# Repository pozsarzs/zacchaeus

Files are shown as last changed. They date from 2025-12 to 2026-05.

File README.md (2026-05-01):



# Zacchaeus Microcomputer
**8-bit microcomputer built from commercially available and home-built components**  

This project is a personal journey back in time to the heroic age of computing:
a newly built, classic 8-bit system, in which I supplement the factory components
with modules of my own design. My goal is to revive the joy of discovery, while
on this new machine, legendary languages such as BASIC, Fortran or Cobol come to
life again.

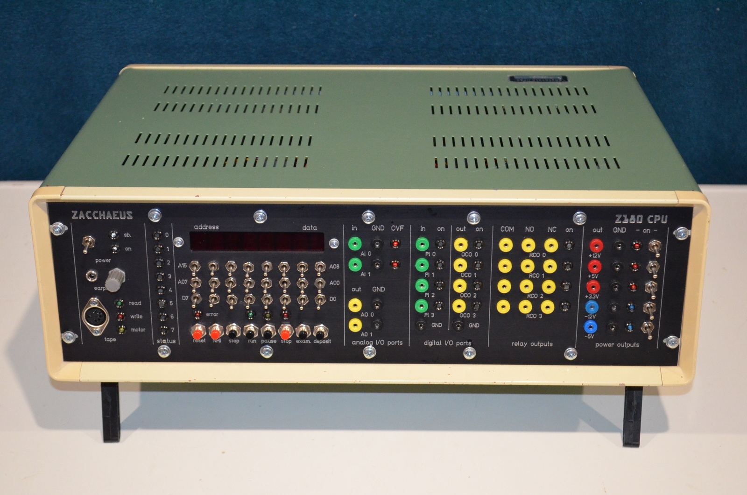
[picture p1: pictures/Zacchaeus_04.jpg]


The computer is built on a motherboard based on the Z180 processor and expansion
cards designed by Stephen C. Cousins. These component descriptions are provided
for completeness and represent the versions available at the time of use.
For more detailed descriptions and the latest updates, please visit the original
author's website ([Small Computer Central](https://smallcomputercentral.com/)).
These components are licensed as _open source_ and _public domain_.

These components are complemented by custom-designed expansion cards and
external peripherals. The custom-designed software are licensed as
_open source_ and hardware are licensed as _public domain_.  

A detailed description of the computer can be found in the
[Zacchaeus computer](https://github.com/pozsarzs/zacchaeus/tree/main/Zacchaeus%20computer) folder.

## External interface box

PEIX is an 8-slot interface connecting legacy _Klöckner-Moeller PS316_ I/O modules
to the Zacchaeus computer via RS-232 serial line with SCRAP protocol. It restores
functionality to these obsolete analog and digital modules.

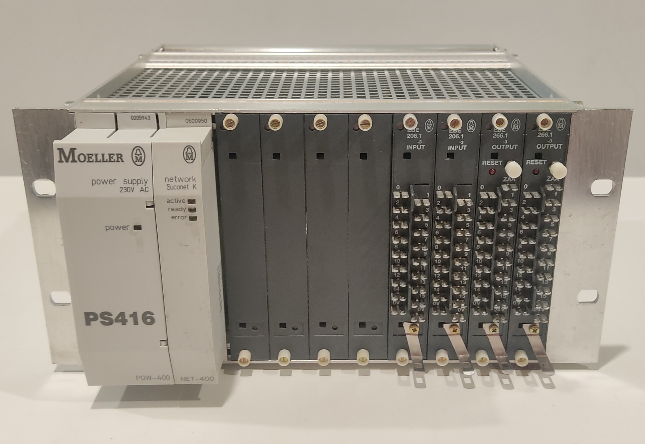
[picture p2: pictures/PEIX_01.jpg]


A detailed description of the interface box can be found in the
[PEIX External interface box](https://github.com/pozsarzs/zacchaeus/tree/main/PEIX%20External%20interface%20box) folder.

## External memory box (EPROM bank)

PEMX is an 8-slot external EPROM bank connected via two PIO ports. It supports
2764 through 27512 EPROMs, including 'A' and CMOS variants with raw data and
lowFAT filesystem.

A detailed description of the memory box can be found in the
[PEMX External memory box](https://github.com/pozsarzs/zacchaeus/tree/main/PEMX%20External%20memory%20box) folder.

---

### My related projects on Github

- [An extended Turing machine implementation for CP/M and DOS](https://github.com/pozsarzs/alanz80x)
- [Turing machine implementation for CP/M and DOS](https://github.com/pozsarzs/alanz80)
- [Simulator for running DATAS machine code for CP/M and DOS](https://github.com/pozsarzs/datassim)
- [The FORTRAN Month](https://github.com/pozsarzs/fortran_month)
- [Synchronized Client Register Access Protocol](https://github.com/pozsarzs/scrap)
- [R128 filesystem](https://github.com/pozsarzs/r128fs)

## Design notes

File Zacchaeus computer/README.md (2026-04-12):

# Zacchaeus Microcomputer
  
## Features

|components |type, size, etc. |
|---|---|
|motherboard |SC126 |
|firmware |RomWBW SCZ180_sc126 v3.5.1 2025-05-21 |
|processor |Z180 processor (33 MHz - at 18.432 MHz) |
|ROM |2 x 512 kB byte Flash memory |
|RAM |512 kB byte RAM |
|bus |BP80 (extended RC2014 bus), 9 sockets |
|disks |32 MB CF card |
| |SD card |
|others |RTC |
|control panel |8 digits hexadecimal LED display |
| |8 data input switch |
| |16 address input switch |
| |8 control button |
|front connectors|1 x tape |
| |1 x earphone |
| |4 x protected digital input 12V |
| |4 x open collector output |
| |4 x NO/NC relay contact output |
| |2 x analog input 0-10V |
| |2 x analog output 0-10V |
| |+12/5/3.3V 3A power outputs |
| |-12/5V 0.5A power outputs |
|back connectors |2 x serial RS-232 (DB9M black) |
| |2 x serial RS-232 TTL (DB9M and DB25M blue)  |
| |2 x paralel TTL (DB25F blue) |
| |1 x CTC TTL (DB9F blue) |
| |1 x spare DB9F (DB9F white) |
| |1 x I<sup>2</sup>C TTL |
| |1 x SPI TTL |
| |1 x Line out |
|power supply |ATX |
|OS |Digital Research CP/M v2.2 |
| |Z-System |

### Internal structure

The SCxxx modules are designed by Stephen C. Cousins, all information about
them can be found at [Small Computer Central](https://smallcomputercentral.com/)
site.

The Pxxx modules were designed by me, their documentation is available on
the [Github](https://github.com/pozsarzs/zacchaeus) and will soon be
available on my [homepage](http://www.pozsarzs.hu).

The machine is housed in a power supply cover (OMSZÖV OE-222) from the 1980s.

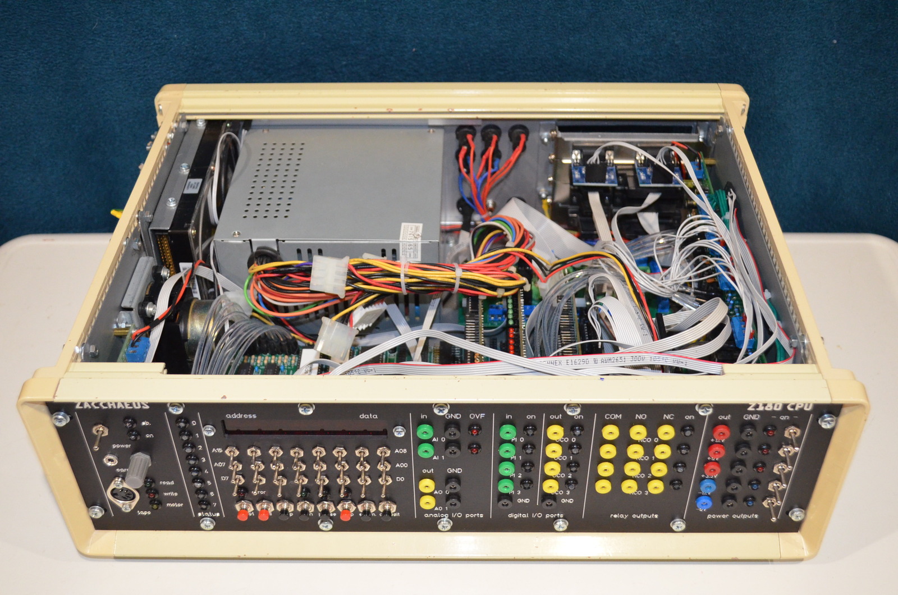
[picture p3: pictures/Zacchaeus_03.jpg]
Appearance


The computer consists of the following components:

|name |function |
|---|---|
|SC126  |[motherboard](https://github.com/pozsarzs/zacchaeus/tree/main/Zacchaeus%20computer/hardware/SC126%20Z180%20motherboard) |
|SC702  |[RCBus backplane](https://github.com/pozsarzs/zacchaeus/tree/main/Zacchaeus%20computer/hardware/SC702%20RCBus%20backplane) |
|SC715  |[RCBus CF module](https://github.com/pozsarzs/zacchaeus/tree/main/Zacchaeus%20computer/hardware/SC715%20RCBus%20CF%20module) |
|SC716  |[RCBus SIO-2 module](https://github.com/pozsarzs/zacchaeus/tree/main/Zacchaeus%20computer/hardware/SC716%20RCBus%20SIO-2%20module) |
|SC717  |[RCBus PIO module](https://github.com/pozsarzs/zacchaeus/tree/main/Zacchaeus%20computer/hardware/SC717%20RCBus%20PIO%20module) |
|SC718  |[RCBus CTC module](https://github.com/pozsarzs/zacchaeus/tree/main/Zacchaeus%20computer/hardware/SC718%20RCBus%20CTC%20module) |
|SC719  |[RCBus DIO module](https://github.com/pozsarzs/zacchaeus/tree/main/Zacchaeus%20computer/hardware/SC719%20RCBus%20DIO%20module) |
|PCOX |[Internal COVOX-style mono sound module with earphone amplifier](https://github.com/pozsarzs/zacchaeus/tree/main/Zacchaeus%20computer/hardware/PCOX%20COVOX%20module)|
|PIOI |[I/O interface module](https://github.com/pozsarzs/zacchaeus/tree/main/Zacchaeus%20computer/hardware/PIOI%20IO%20Interface%20module) |
|PMAN-IF|[Manual control panel interface module](https://github.com/pozsarzs/zacchaeus/tree/main/Zacchaeus%20computer/hardware/PMAN-IF%20Interface%20module)|
|PMAN-DP|[Manual control panel display module](https://github.com/pozsarzs/zacchaeus/tree/main/Zacchaeus%20computer/hardware/PMAN-DP%20Display%20module) |
|PMAN-SW|[Manual control panel switch module](https://github.com/pozsarzs/zacchaeus/tree/main/Zacchaeus%20computer/hardware/PMAN-SW%20Switch%20module) |
|PPOW |[Power distribution module with external fuses](https://github.com/pozsarzs/zacchaeus/tree/main/Zacchaeus%20computer/hardware/PPOW%20Power%20distribution%20module)  |
|PSPK |[Speaker amplifier module with speaker](https://github.com/pozsarzs/zacchaeus/tree/main/Zacchaeus%20computer/hardware/PSPK%20Speaker%20amplifier%20module) |
|MCS-51M|[2 pcs. TTL/RS232 level shifter module](https://github.com/pozsarzs/zacchaeus/tree/main/Zacchaeus%20computer/hardware/MCS-51M%20RS232%20level%20shifter%20module) |
| |ATX PC power supply |

### Planned modules

|name |function |
|---|---|
|PANA |Analog input/output module (2AI, 2AO, 0-10V) |
|PTVI |Monochrome Graphics Adapter with external RF modulator |
|PTAP |[Tape and speaker interface module](https://github.com/pozsarzs/zacchaeus/tree/main/Zacchaeus%20computer/hardware/PTAP%20Tape%20interface%20module)|

---

## Hardware

In addition to the contents of the subdirectories, this description contains
all information that applies to the computer as a whole or to several cards
together.

_README.md_ contains all textual information in the directory of self-designed
hardware elements, _*description.pdf_ provides the same information in the
directory of purchased devices. In these, the _README.md_ only contains the
current settings and information.

### Physical memory address table

The motherboard provides two Flash ROM sockets, enabling two firmware images to
be installed simultaneously; on the SC126, these typically contain the Small
Computer Monitor (SCM) in one device and RomWBW in the other.

The physical memory consists of 512 kB of Flash ROM at the lower half of the
address space and 512 kB of RAM at the upper half, with the Z180 memory
management unit mapping portions of this physical memory into the 64 kB logical
address space defined by the Z80/Z180 instruction set.

|From  |To |Function |
|-----:|-----:|---|
|80000h|FFFFFh|RAM (512k bytes) |
|00000h|7FFFFh|Flash ROM (512k bytes)|

### I/O address table

|From|To |Module |Function |Note |
|---:|--:|---|---|---|
|00h |0Bh| | | |
|0Ch | |SC126  |system I/O port (RTC, SPI and I2C)| |
|0Dh | |SC126  |LED output port | |
|0Eh |0Fh| | | |
|10h |17h|SC715  |CF module | |
|18h |2Fh| | | |
|30h | |SC719  |DIO for PIOI module | |
|31h | |PCOX |Covox module | |
|40h |4Bh|PMAN-IF|Manual control panel interface | |
|50h |53h|PTAP |Tape and speaker interface |planned|
|60h |6xh|PANA |analog I/O module |planned|
|3Ch |67h| | | |
|68h |6Bh|SC717  |PIO module | |
|6Ch |7Fh| | | |
|80h |83h|SC716  |SIO/2 module | |
|84h |87h| | | |
|88h |8Bh|SC718  |CTC module | |
|8Ch |BFh| | | |
|C0h |FFh|SC126  |Z180’s internal I/O registers | |

### IRQ table

|Number|Module|Function |Note |
|:----:|---|---|---|
|NMI | | | |
|INT0  |SC718 |timed interrupt|priority: 1st|
|INT1  | | | |
|INT2  | | | |

### BP80 extended bus

SC126 has 80-pin expansion sockets which are an extended RC2014 bus, known as
Backplane-80 (or BP80). This is an unofficial variant of the RC2014 Bus.

|Pin |Signal name|Dir.|From-to |Pin |Signal name|Dir.|From-to |
|---:|---|----|---|---:|---|----|---|
| 41 | n41 | |not yet assigned|  1 | A15 | <- |CPU-A15 |
| 42 | n42 | |not yet assigned|  2 | A14 | <- |CPU-A14 |
| 43 | n43 | |not yet assigned|  3 | A13 | <- |CPU-A13 |
| 44 | n44 | |not yet assigned|  4 | A12 | <- |CPU-A12 |
| 45 | n45 | |not yet assigned|  5 | A11 | <- |CPU-A11 |
| 46 | n46 | |not yet assigned|  6 | A10 | <- |CPU-A10 |
| 47 | n47 | |not yet assigned|  7 | A9 | <- |CPU-A9 |
| 48 | n48 | |not yet assigned|  8 | A8 | <- |CPU-A8 |
| 49 | A23 | |not used |  9 | A7 | <- |CPU-A7 |
| 50 | A22 | |not used | 10 | A6 | <- |CPU-A6 |
| 51 | A21 | |not used | 11 | A5 | <- |CPU-A5 |
| 52 | A20 | |not used | 12 | A4 | <- |CPU-A4 |
| 53 | A19 | <- |CPU-A19 | 13 | A3 | <- |CPU-A3 |
| 54 | A18 | <- |CPU-A18_Tout | 14 | A2 | <- |CPU-A2 |
| 55 | A17 | <- |CPU-A19 | 15 | A1 | <- |CPU-A1 |
| 56 | A16 | <- |CPU-A19 | 16 | A0 | <- |CPU-A0 |
| 57 | GND | -  |power supply | 17 | GND | -  |power supply |
| 58 | +5V | <- |power supply | 18 | +5V | <- |power supply |
| 59 | /RFSH | <- |CPU-/RFSH | 19 | /M1 | <- |/M1 |
| 60 | PAGE | |not used | 20 | /RESET | <- |reset circuit|
| 61 | CLK2 | |not used | 21 | CLK | <- |CPU-PHI |
| 62 | /BUSAK | <- |CPU-/BUSACK | 22 | /INT | -> |CPU-/INT0 |
| 63 | /HALT | <- |CPU-/HALT | 23 | /MREQ | <- |CPU-/MEMRQ |
| 64 | /BUSRQ | -> |CPU-/BUSREQ | 24 | /WR | <- |CPU-/WR |
| 65 | /WAIT | -> |CPU-/WAIT | 25 | /RD | <- |CPU-/RD |
| 66 | /NMI | -> |CPU-/NMI | 26 | /IORQ | <- |CPU-/IORQ |
| 67 | D8 | |not used | 27 | D0 | <->|CPU-D0 |
| 68 | D9 | |not used | 28 | D1 | <->|CPU-D1 |
| 69 | D10 | |not used | 29 | D2 | <->|CPU-D2 |
| 70 | D11 | |not used | 30 | D3 | <->|CPU-D3 |
| 71 | D12 | |not used | 31 | D4 | <->|CPU-D4 |
| 72 | D13 | |not used | 32 | D5 | <->|CPU-D5 |
| 73 | D14 | |not used | 33 | D6 | <->|CPU-D6 |
| 74 | D15 | |not used | 34 | D7 | <->|CPU-D7 |
| 75 | TX2 | <- |CPU-TXA1 | 35 | TX | <- |CPU-TXA0 |
| 76 | RX2 | -> |CPU-RXA1 | 36 | RX | -> |CPU-RXA0 |
| 77 | USER5 | |not used | 37 | USER1 | |not used |
| 78 | USER6 | |I2C SCL | 38 | USER2 | |not used |
| 79 | USER7 | |I2C SDA | 39 | USER3 | |not used |
| 80 | USER8 | |IEI | 40 | USER4 | |IEO |

#### Using USERn lines

USERn lines are the "free-to-use" lines of the RC2014 bus system. They were
created to keep the system flexible and allow users to add features that are
not part of the standard according to their individual needs.

_On the motherboard:_  

|Pin|Signal name|SC126 |
|--:|---|---|
| 37|USER1 | |
| 38|USER2 | |
| 39|USER2 | |
| 40|USER4 |IEO |
| 77|USER5 | |
| 78|USER6 |I2C SCL [1]|
| 79|USER7 |I2C SDA [2]|
| 80|USER8 |IEI |

Jumpering:  

[1]: SC126 JP5 close 1-2 (default: opened)
[2]: SC126 JP5 close 3-4 (default: opened) 

_On the backplane:_  

The SC-702 backplane forwards all lines straight with basic jumpering, but if
necessary, daisy-chain interrupt lines can be created.

_On expansion cards:_  

|Pin|Signal name|SC715|SC716  |SC717  |SC718 |SC719|PCOX|
|--:|---|-----|---|---|---|-----|----|
| 37|USER1 | | | |/CINT1 [8] | | |
| 38|USER2 | |IEI [4]|IEI [6]|IEI [9] | | |
| 39|USER2 | |IEO [5]|IEO [7]|IEO [10] | | |
| 40|USER4 | | | | | | |
| 77|USER5 | | | |/CINT2 [11]| | |
| 78|USER6 | | | | | | |
| 79|USER7 | | | | | | |
| 80|USER8 | | | | | | |

Jumpering:  

[4]: SC716 JP8 close 1-2  
[5]: SC716 JP9 close 1-2  
[6]: SC717 JP2 close 1-2  
[7]: SC717 JP3 close 1-2  
[8]: SC718 JP9 close 1-2  
[9]: SC718 JP8 close 1-2  
[10]: SC718 JP7 close 1-2  
[11]: SC718 JP10 close 1-2  

**Other special lines**  

|Pin|Signal name|User function |
|--:|---|---|
| 61|CLK2 |Speaker signal SC718/CTC2 -> PTAP|
| 75|TX2 |Serial data  SC126 -> PTAP |
| 76|RX2 |Serial data  SC126 <- PTAP |

**How to jumper the USERn and TX/RX lines of the bus**  

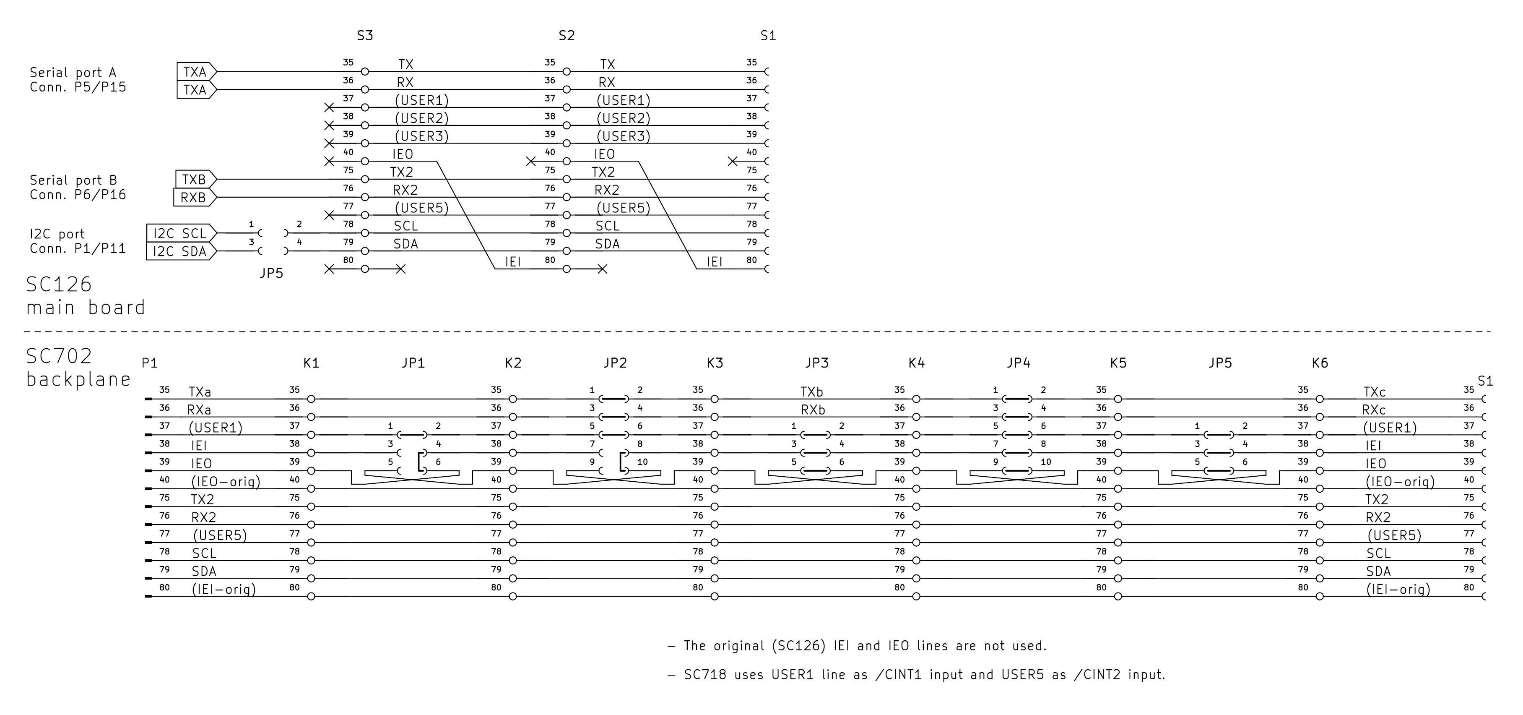
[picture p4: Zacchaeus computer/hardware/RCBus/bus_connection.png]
USERn and TX/RX lines
<kbd></kbd>

### Modules in the expansion sockets

|Unit |Socket|Modul  |Function |Note |
|---|---|---|---|---|
|motherboard|  S2  |PCOX |COVOX module | |
|motherboard|  S3  |PMAN-IF|manual control panel interface| |
|backplane  |  K1  |SC718  |CTC module | |
|backplane  |  K2  |SC716  |SIO/2 module | |
|backplane  |  K3  |SC719  |DIO for PIOI module | |
|backplane  |  K4  |PTAP |tape and speaker interface |planned|
|backplane  |  K5  |PANA |analog I/O module |planned|
|backplane  |  K6  |SC717  |PIO module | |
|backplane  |  P1  |SC715  |CF module | |

The order is important because of daisy-chain interrupt handling.

---

## Software

This hardware is accompanied by a collection of functions (written in
Assembly), a Turbo Pascal include file, and a compiled, relocatable
object module - the latter of which can be linked to your own programs.

The [motherboard library](https://github.com/pozsarzs/zacchaeus/tree/main/Zacchaeus%20computer/software/SC126%20Z180%20motherboard)
contains the current contents of the two ROMs, the newer version can be
downloaded from the internet.

### Utilities

- [_coxplayer.com_](https://github.com/pozsarzs/zacchaeus/tree/main/Zacchaeus%20computer/software/PCOX%20COVOX%20module):
  Plays a raw audio file using the PCOX module. (soon)
- [_coxpiano.com_](https://github.com/pozsarzs/zacchaeus/tree/main/Zacchaeus%20computer/software/PCOX%20COVOX%20module):
  A utility for checking the PCOX module. (soon)
- [_pioitest.com_](https://github.com/pozsarzs/zacchaeus/tree/main/Zacchaeus%20computer/software/PIOI%20IO%20Interface%20module):
  A utility for checking the PIOI module.
- [_mancheck.com_](https://github.com/pozsarzs/zacchaeus/tree/main/Zacchaeus%20computer/software/PMAN-IF%20Interface%20module):
  A utility for checking the PMAN module. (soon)
- [_manitou.com_](https://github.com/pozsarzs/zacchaeus/tree/main/Zacchaeus%20computer/software/PMAN-IF%20Interface%20module):
  A monitor program that uses a manual control panel. (soon)
- [_tapload.com_](https://github.com/pozsarzs/zacchaeus/tree/main/Zacchaeus%20computer/software/PTAP%20Tape%20interface%20module):
  Loads data from tape into memory starting at a specific RAM address and can optionally execute it. (soon)
- [_tapsave.com_](https://github.com/pozsarzs/zacchaeus/tree/main/Zacchaeus%20computer/software/PTAP%20Tape%20interface%20module):
  Saves data from a selected memory range to tape. (soon)
- [_tapdump.com_](https://github.com/pozsarzs/zacchaeus/tree/main/Zacchaeus%20computer/software/PTAP%20Tape%20interface%20module):
  Saves data from tape to disk or displays it. (soon)

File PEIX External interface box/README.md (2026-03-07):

# External interface box

## About equipment

The PEIX serves as an 8-slot external interface, designed to integrate legacy
_Klöckner-Moeller PS316_ I/O modules with the Zacchaeus computer. Although the
PS316 family has been obsolete since the mid-2000s, this circuit enables
continued functionality by interfacing with the system's original analog and
digital I/O modules.

The device is controlled by a circuit built with an 87C51 microcontroller.
It is responsible for controlling the PLC modules and communicating with
Zacchaeus via the RS-232 serial port.

Adapting the device's variously controllable, undocumented modules to a
non-original device is a complex, multi-step task, so I implement the
microcontroller-based interface on a prototype board of the same size as the
other modules.

The documentation for PLC modules contains only what is necessary to understand
the control. Modules can also be used perfectly as "black boxes" if we know
their characteristics and control method.

The interface is developed in a modular manner in four main phases. At the end
of each phase, a functional system is obtained, which is expanded according to
the following schedule:

- [ ] **Basic infrastructure:** Development of the control and communication
      board, SCRAP protocol, API, and monitor program.
- [ ] **Digital I/O:** Circuit decoding, matching, and software support of the
      digital input and output boards.
- [ ] **Analog Output:** Circuit decoding, hardware integration of the analog
      output board and implementation of related functions.
- [ ] **Analog Input:** Circuit decoding, matching and full software management of
      the analog input board.

This equipment requires 230 V AC for operation.

## Mechanical structure

The device remains in the original PS 316.x08 housing, which also includes the
backplane. The built-in power supply was from the PS416 PLC, the control and
communication module follows the design of the PS416 NET-400 module. Their
front panel also hides the permanently connected connectors. The I/O modules
are made for the older PS316 system. The original connectors of the digital
modules were not used, the front panel contacts are ideal for stable connection
of crocodile clips. Remember, this is just a 'toy', it will not perform a
serious control task.

**Modules**  

|Slot|Sign |Function |Note|
|----|---|---|----|
| #0 | |power supply | |
| #1 |PEIX |control and communication| |
| #2 | | | |
| #3 | | | |
| #4 | | | |
| #5 | | | |
| #6 |EBE 206.1|digital input | |
| #7 |EBE 206.1|digital input | |
| #8 |EBE 266.1|digital output | |
| #9 |EBE 266.1|digital output | |

## Jumper settings

|Module |Num |Sign |Function |State |Note |
|---|:--:|---|---|:---:|---|
|PEIX |JP1 |EXT ROM |enable external ROM |closed | |
|PEIX |JP2 |AKT LED |MCU ACT LED from port PC7|1-2 closed| |
|EBE 206.1@6|SW1 |'DA0-5  |card address |10100000  |switch 1..8 |
|EBE 206.1@7|SW1 |'DA0-5  |card address |01100000  |switch 1..8 |
|EBE 266.1@8|SW1 |'DA0-5  |card address |11100000  |switch 1..8 |
|EBE 266.1@9|SW1 |'DA0-5  |card address |00010000  |switch 1..8 |

## Connection with others

|Module|Num |Sign|Function |Sign|Num |Module |
|---|:--:|----|---|----|:----:|---|
|PEIX  |J7/2|RXD |received data (DCE) |RXD |DB9M/2|serial port|
|PEIX  |J7/3|TXD |transmitted data (DCE)|TXD |DB9M/3|serial port|
|PEIX  |J7/5|RXD |GND |GND |DB9M/5|serial port|

## Software

The software in the control and communication module of the PEIX is responsible
for the I/O cards and the communication between itself and the control computer.

The program stores the analog and digital signals coming from the I/O cards and
to be written there in Modbus registers. Reading and writing are repeated
periodically, as long as there are no incoming telegrams on the serial port.

External data exchange takes place via an interrupt-based serial connection.
This ensures a fast and reliable connection between the hardware and the
monitoring system. The module communicates with the computer via the
[SCRAP](https://github.com/pozsarzs/scrap) protocol.

## Legal disclaimer & interoperability statement

### Purpose of this project

This project involves the reverse engineering of the connection points and
interface logic of the Moeller/Eaton PS316 I/O cards. The sole purpose of this
work is to achieve interoperability between legacy industrial hardware and
modern control systems, ensuring the continued use and maintenance of existing
equipment (Right to Repair).

### Legal basis (EU & USA)

This project is conducted and shared in compliance with the following legal
frameworks:

**European Union:** In accordance with Directive 2009/24/EC, reverse engineering
for the purpose of interoperability is legally permitted. The data provided here
is the result of independent observation and testing of legally acquired
hardware.

**United States:** This project falls under the Fair Use doctrine and the DMCA
Section 1201(f) exemption. These provisions allow for the circumvention of
access controls (if any) and the analysis of hardware for the sole purpose of
enabling a software program or hardware device to exchange and use information
with other systems.

### Status of the PS316 system

**Legacy hardware:** The PS316 series, originally manufactured by Moeller (now
part of Eaton), is a legacy product line that has reached End-of-Life (EOL) and
End-of-Support (EOS) status.

**Commercial non-competition:** This project does not compete with any current
product offered by the original manufacturer. Documentation for these cards is
no longer commercially available or supported by the vendor.

**Functional information:** The information shared (such as pinouts, voltage
levels, and signal paths) is strictly functional and does not constitute a
"creative work" protected by copyright.

### Intellectual property compliance

**No proprietary code:** This repository does not contain any proprietary
firmware, binary blobs, or copyrighted software extracted from the devices.

**Independent implementation:** All schematics, drivers, and adapter designs
provided here are original works created by the author based on the discovered
functional parameters.

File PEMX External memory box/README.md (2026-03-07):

# External memory box

## About equipment

The PEMX is an external EPROM bank that connects to the computer (SC717 module)
via two PIO ports. The device contains eight ZIF-type EPROM sockets that can
accommodate the following types of EPROMs: 2764, 27128, 27256 and 27512 (and
their "A" and CMOS variants). The device does not support the use of smaller
EPROMs. Only one EPROM can be used at a time and they do not form a contiguous
memory area.

The EPROM content is raw code or a set of files stored in the lowFAT file
system. The raw code is handled by the _emxdump_ utility, displayed on the
screen or saved to disk in two formats. The EPROMs in the lowFAT system are
handled by the _emxload_ utility, which lists their table of contents, saves
them to disk in binary form, loads them into memory (to a definable location)
and runs them if necessary.

This equipment requires 230V AC for operation.

## Jumper settings

|Module|Num |Sign|Function |State |Note |
|---|:--:|----|---|:---:|---|
|SC717 |JP1 |A7-0|I/O address |01101000| |
|SC717 |JP2 |IEI |daisy-chain INT line|closed  | |
|SC717 |JP3 |IEO |daisy-chain INT line|closed  | |
|PEMX  |JP1 |1-2 |type: 27512 |closed  |BANK #0|
|PEMX  |JP1 |3-2 |type: 2764..27256 |closed  |BANK #0|
|PEMX  |JP2 |1-2 |type: 27256, 27512  |closed  |BANK #0|
|PEMX  |JP2 |3-2 |type: 2764, 27128 |closed  |BANK #0|
|PEMX  |JP3 |1-2 |type: 27512 |closed  |BANK #4|
|PEMX  |JP3 |3-2 |type: 2764..27256 |closed  |BANK #4|
|PEMX  |JP4 |1-2 |type: 27256, 27512  |closed  |BANK #4|
|PEMX  |JP4 |3-2 |type: 2764, 27128 |closed  |BANK #4|
|PEMX  |JP5 |1-2 |type: 27512 |closed  |BANK #1|
|PEMX  |JP5 |3-2 |type: 2764..27256 |closed  |BANK #1|
|PEMX  |JP6 |1-2 |type: 27256, 27512  |closed  |BANK #1|
|PEMX  |JP6 |3-2 |type: 2764, 27128 |closed  |BANK #1|
|PEMX  |JP7 |1-2 |type: 27512 |closed  |BANK #5|
|PEMX  |JP7 |3-2 |type: 2764..27256 |closed  |BANK #5|
|PEMX  |JP8 |1-2 |type: 27256, 27512  |closed  |BANK #5|
|PEMX  |JP8 |3-2 |type: 2764, 27128 |closed  |BANK #5|
|PEMX  |JP9 |1-2 |type: 27512 |closed  |BANK #2|
|PEMX  |JP9 |3-2 |type: 2764..27256 |closed  |BANK #2|
|PEMX  |JP10|1-2 |type: 27256, 27512  |closed  |BANK #2|
|PEMX  |JP10|3-2 |type: 2764, 27128 |closed  |BANK #2|
|PEMX  |JP11|1-2 |type: 27512 |closed  |BANK #6|
|PEMX  |JP11|3-2 |type: 2764..27256 |closed  |BANK #6|
|PEMX  |JP12|1-2 |type: 27256, 27512  |closed  |BANK #6|
|PEMX  |JP12|3-2 |type: 2764, 27128 |closed  |BANK #6|
|PEMX  |JP13|1-2 |type: 27512 |closed  |BANK #3|
|PEMX  |JP13|3-2 |type: 2764..27256 |closed  |BANK #3|
|PEMX  |JP14|1-2 |type: 27256, 27512  |closed  |BANK #3|
|PEMX  |JP14|3-2 |type: 2764, 27128 |closed  |BANK #3|
|PEMX  |JP15|1-2 |type: 27512 |closed  |BANK #7|
|PEMX  |JP15|3-2 |type: 2764..27256 |closed  |BANK #7|
|PEMX  |JP16|1-2 |type: 27256, 27512  |closed  |BANK #7|
|PEMX  |JP16|3-2 |type: 2764, 27128 |closed  |BANK #7|

## Connection with others

Internal ribbon cable between main board and DB25F connector on the back panel:

|Module|Num  |Sign|Function |Sign|Num |Module|
|---|:---:|----|---|----|:----:|---|
|board |J3/1 |AD0 |register selector and output enable|AD0 |J3A/1 |back  |
|board |J3/2 |AD2 |register selector and output enable|AD2 |J3A/2 |back  |
|board |J3/3 |AD4 |register write clock |AD4 |J3A/3 |back  |
|board |J3/4 |AD6 |register input data |AD6 |J3A/4 |back  |
|board |J3/5 |GND |GND |GND |J3A/5 |back  |
|board |J3/6 |J5/1|spare | |J3A/6 |back  |
|board |J3/7 |J5/2|spare | |J3A/7 |back  |
|board |J3/8 |J5/3|spare | | | |
|board |J3/9 |GND |GND |GND |J3A/9 |back  |
|board |J3/10|BD0 |output data |BD0 |J3A/10|back  |
|board |J3/11|BD2 |output data |BD2 |J3A/11|back  |
|board |J3/12|BD4 |output data |BD4 |J3A/12|back  |
|board |J3/13|BD6 |output data |BD6 |J3A/13|back  |
|board |J3/14|AD1 |register selector and output enable|AD1 |J3A/14|back  |
|board |J3/15|AD3 |register selector and output enable|AD3 |J3A/15|back  |
|board |J3/16|AD5 |register input data |AD5 |J3A/16|back  |
|board |J3/17|AD7 |register input data |AD7 |J3A/17|back  |
|board |J3/18|GND |GND |GND |J3A/18|back  |
|board |J3/19|J1/1|spare | |J3A/19|back  |
|board |J3/20|J1/2|spare | |J3A/20|back  |
|board |J3/21|J1/3|spare | | | |
|board |J3/22|GND |GND |GND |J3A/21|back  |
|board |J3/23|BD1 |output data |BD1 |J3A/22|back  |
|board |J3/24|BD3 |output data |BD3 |J3A/23|back  |
|board |J3/25|BD5 |output data |BD5 |J3A/24|back  |
|board |J3/26|BD7 |output data |BD7 |J3A/25|back  |

Y-cable between equipment and two PIO ports:

|Module|Num  |Sign|Function |Sign|Num |Module|
|---|:---:|----|---|----|:---:|---|
|PIO #1| 1| RDY|READY |RDY |J3B/6 |back  |
|PIO #1| 2| P0 |data line|AD0 |J3B/1 |back  |
|PIO #1| 3| P1 |data line|AD1 |J3B/14 |back  |
|PIO #1| 4| P2 |data line|AD2 |J3B/2 |back  |
|PIO #1| 5| P3 |data line|AD3 |J3B/15 |back  |
|PIO #1| 6| P4 |data line|AD4 |J3B/3 |back  |
|PIO #1| 7| P5 |data line|AD5 |J3B/16 |back  |
|PIO #1| 8| P6 |data line|AD6 |J3B/4 |back  |
|PIO #1| 9| P7 |data line|AD7 |J3B/17 |back  |
|PIO #1| 10|-STB|-STROBE  |-STB|J3B/19 |back  |
|PIO #1|18-25| GND|GND |GND |J3B/5, 18 |back  |
|PIO #2| 1| RDY|READY |RDY |J3B/20 |back  |
|PIO #2| 2| P0 |data line|BD0 |J3B/10 |back  |
|PIO #2| 3| P1 |data line|BD1 |J3B/22 |back  |
|PIO #2| 4| P2 |data line|BD2 |J3B/11 |back  |
|PIO #2| 5| P3 |data line|BD3 |J3B/23 |back  |
|PIO #2| 6| P4 |data line|BD4 |J3B/12 |back  |
|PIO #2| 7| P5 |data line|BD5 |J3B/24 |back  |
|PIO #2| 8| P6 |data line|BD6 |J3B/13 |back  |
|PIO #2| 9| P7 |data line|BD7 |J3B/25 |back  |
|PIO #2| 10|-STB|-STROBE  |-STB|J3B/7 |back  |
|PIO #2|18-25| GND|GND |GND |J3B/9, 21 |back  |

## Software

This hardware is accompanied by a collection of functions (written in
Assembly), a Turbo Pascal include file, and a compiled, relocatable
object module—the latter of which can be linked to your own programs.

### Utilities

- [_emxdump.com_](https://github.com/pozsarzs/zacchaeus/tree/main/PEMX%20External%20memory%20box/software):
  Data listing and saving utility. Lists the entire contents of the selected
  EPROM in hexadecimal and character format or saves them to disk in the same or
  binary format.

- [_emxload.com_](https://github.com/pozsarzs/zacchaeus/tree/main/PEMX%20External%20memory%20box/software):
  Data loading utility for EPROM with lowFAT filesystem. Displays the table of
  contents of the selected EPROM, saves it in binary format, loads it into
  memory, and if necessary, starts the selected entry.

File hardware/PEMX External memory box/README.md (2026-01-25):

# Zacchaeus Microcomputer

## Hardware/PEMX External memory box

### Directory content

|file |description |
|---|---|
|\[pemx\] |KiCAD files |
|pemx-B_Cu.pdf |solder side of the PCB |
|pemx-F_Cu.pdf |component side of the PC |
|pemx-F_Silkscreen.pdf|silkscreen of the PCB |
|pemx-gerber.zip |Gerber files for manufacturing|
|pemx.pdf |schematic drawing |
|eprom_pinout.md |comparison of EPROM's pinout  |

### About module

The PEMX is an 8-slot external EPROM bank that connects to the computer via two
PIO ports (SC717 module). The bank can use the 2764, 27128, 27256 and 27512
EPROMs and their "A" and CMOS versions. The selected EPROM is not built into the
machine's memory area, but can be copied to disk or loaded into memory (and run)
using utility programs. This equipment requires 230V AC for operation.

### Jumper settings

|Module|Num |Sign|Function |State |Note |
|---|:--:|----|---|:---:|---|
|SC717 |JP1 |A7-0|I/O address |01101000| |
|SC717 |JP2 |IEI |daisy-chain INT line|closed  | |
|SC717 |JP3 |IEO |daisy-chain INT line|closed  | |
|PEMX  |JP1 |1-2 |type: 27512 |closed  |BANK #0|
|PEMX  |JP1 |3-2 |type: 2764..27256 |closed  |BANK #0|
|PEMX  |JP2 |1-2 |type: 27256, 27512  |closed  |BANK #0|
|PEMX  |JP2 |3-2 |type: 2764, 27128 |closed  |BANK #0|
|PEMX  |JP3 |1-2 |type: 27512 |closed  |BANK #4|
|PEMX  |JP3 |3-2 |type: 2764..27256 |closed  |BANK #4|
|PEMX  |JP4 |1-2 |type: 27256, 27512  |closed  |BANK #4|
|PEMX  |JP4 |3-2 |type: 2764, 27128 |closed  |BANK #4|
|PEMX  |JP5 |1-2 |type: 27512 |closed  |BANK #1|
|PEMX  |JP5 |3-2 |type: 2764..27256 |closed  |BANK #1|
|PEMX  |JP6 |1-2 |type: 27256, 27512  |closed  |BANK #1|
|PEMX  |JP6 |3-2 |type: 2764, 27128 |closed  |BANK #1|
|PEMX  |JP7 |1-2 |type: 27512 |closed  |BANK #5|
|PEMX  |JP7 |3-2 |type: 2764..27256 |closed  |BANK #5|
|PEMX  |JP8 |1-2 |type: 27256, 27512  |closed  |BANK #5|
|PEMX  |JP8 |3-2 |type: 2764, 27128 |closed  |BANK #5|
|PEMX  |JP9 |1-2 |type: 27512 |closed  |BANK #2|
|PEMX  |JP9 |3-2 |type: 2764..27256 |closed  |BANK #2|
|PEMX  |JP10|1-2 |type: 27256, 27512  |closed  |BANK #2|
|PEMX  |JP10|3-2 |type: 2764, 27128 |closed  |BANK #2|
|PEMX  |JP11|1-2 |type: 27512 |closed  |BANK #6|
|PEMX  |JP11|3-2 |type: 2764..27256 |closed  |BANK #6|
|PEMX  |JP12|1-2 |type: 27256, 27512  |closed  |BANK #6|
|PEMX  |JP12|3-2 |type: 2764, 27128 |closed  |BANK #6|
|PEMX  |JP13|1-2 |type: 27512 |closed  |BANK #3|
|PEMX  |JP13|3-2 |type: 2764..27256 |closed  |BANK #3|
|PEMX  |JP14|1-2 |type: 27256, 27512  |closed  |BANK #3|
|PEMX  |JP14|3-2 |type: 2764, 27128 |closed  |BANK #3|
|PEMX  |JP15|1-2 |type: 27512 |closed  |BANK #7|
|PEMX  |JP15|3-2 |type: 2764..27256 |closed  |BANK #7|
|PEMX  |JP16|1-2 |type: 27256, 27512  |closed  |BANK #7|
|PEMX  |JP16|3-2 |type: 2764, 27128 |closed  |BANK #7|

### Connection with others

Internal ribbon cable between main board and DB25F connector on the back panel:

|Module|Num  |Sign|Function |Sign|Num |Module|
|---|:---:|----|---|----|:----:|---|
|board |J3/1 |AD0 |register selector and output enable|AD0 |J3A/1 |back  |
|board |J3/2 |AD2 |register selector and output enable|AD2 |J3A/2 |back  |
|board |J3/3 |AD4 |register write clock |AD4 |J3A/3 |back  |
|board |J3/4 |AD6 |register input data |AD6 |J3A/4 |back  |
|board |J3/5 |GND |GND |GND |J3A/5 |back  |
|board |J3/6 |J5/1|spare | |J3A/6 |back  |
|board |J3/7 |J5/2|spare | |J3A/7 |back  |
|board |J3/8 |J5/3|spare | |J3A/8 |back  |
|board |J3/9 |GND |GND |GND |J3A/9 |back  |
|board |J3/10|BD0 |output data |BD0 |J3A/10|back  |
|board |J3/11|BD2 |output data |BD2 |J3A/11|back  |
|board |J3/12|BD4 |output data |BD4 |J3A/12|back  |
|board |J3/13|BD6 |output data |BD6 |J3A/13|back  |
|board |J3/14|AD1 |register selector and output enable|AD1 |J3A/14|back  |
|board |J3/15|AD3 |register selector and output enable|AD3 |J3A/15|back  |
|board |J3/16|AD5 |register input data |AD5 |J3A/16|back  |
|board |J3/17|AD7 |register input data |AD7 |J3A/17|back  |
|board |J3/18|GND |GND |GND |J3A/18|back  |
|board |J3/19|J1/1|spare | |J3A/19|back  |
|board |J3/20|J1/2|spare | | | |
|board |J3/21|J1/3|spare | |J3A/20|back  |
|board |J3/22|GND |GND |GND |J3A/21|back  |
|board |J3/23|BD1 |output data |BD1 |J3A/22|back  |
|board |J3/24|BD3 |output data |BD3 |J3A/23|back  |
|board |J3/25|BD5 |output data |BD5 |J3A/24|back  |
|board |J3/26|BD7 |output data |BD7 |J3A/25|back  |

Y-cable between equipment and two PIO ports:

|Module|Num|Sign|Function |Sign|Num |Module|
|---|:-:|----|---|----|:----:|---|
|PIO #1|  2| P0 |data line|AD0 |J3A/1 |back  |
|PIO #1|  4| P2 |data line|AD2 |J3A/2 |back  |
|PIO #1|  6| P4 |data line|AD4 |J3A/3 |back  |
|PIO #1|  8| P6 |data line|AD6 |J3A/4 |back  |
|PIO #1| 18|GND |GND |GND |J3A/5 |back  |
|PIO #1|  3| P1 |data line|AD1 |J3A/14|back  |
|PIO #1|  5| P3 |data line|AD3 |J3A/15|back  |
|PIO #1|  7| P5 |data line|AD5 |J3A/16|back  |
|PIO #1|  9| P7 |data line|AD7 |J3A/17|back  |
|PIO #1| 25|GND |GND |GND |J3A/18|back  |
|PIO #2|  2| P0 |data line|BD0 |J3A/10|back  |
|PIO #2|  4| P2 |data line|BD2 |J3A/11|back  |
|PIO #2|  6| P4 |data line|BD4 |J3A/12|back  |
|PIO #2|  8| P6 |data line|BD6 |J3A/13|back  |
|PIO #2| 18|GND |GND |GND |J3A/9 |back  |
|PIO #2|  3| P1 |data line|BD1 |J3A/22|back  |
|PIO #2|  5| P3 |data line|BD3 |J3A/23|back  |
|PIO #2|  7| P5 |data line|BD5 |J3A/24|back  |
|PIO #2|  9| P7 |data line|BD7 |J3A/25|back  |
|PIO #2| 25|GND |GND |GND |J3A/21|back  |

### Softwares

This hardware comes a function collection (in assembly language) and a compiled,
relocatable object code module, the latter of which can be linked to our own
program. In addition, two user programs were written to dump and load the
contents of memory.

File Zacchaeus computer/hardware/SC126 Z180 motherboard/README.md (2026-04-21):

# Zacchaeus Microcomputer

## Hardware/SC126 Z180 motherboard

### Directory content

|file |description |
|---|---|
|SC126.jpg |picture about assembled board |
|SC126 description.pdf |detailed description |
|SC126 kit contents.pdf|contents of the kit available for purchase|
|SC126 schematic.pdf |schematic drawing |

### About module

This is a commercially available motherboard built with a Z180 processor
designed by Stephen C. Cousins. You can find the details in the original PDF
files.

### Jumper settings

|Module|Num |Sign|Function |State |Note|
|---|:--:|----|---|:---:|----|
|SC126 |JP1 | |ROMWBW write protect |1-2 closed| |
|SC126 |JP2 | |SCM S6 write protect |1-2 closed| |
|SC126 |JP3 | |flash select |2-3 closed| |
|SC126 |JP4 | |DCD0/DREQ1 select |1-2 closed| |
|SC126 |JP5 | |I<sup>2</sup>C to bus socket|all opened| |
|SC126 |P4  | |+5V to serial connector P5  |closed | |
|SC126 |P7  | |+5V to serial connector P6  |opened | |

### Connection with others

|Module |Num |Sign|Function|Sign|Num |Module |
|---|:--:|----|---|----|:--:|---|
|PMAN-SW|J4/1| |GND | |P8/1|SC126 |
|PMAN-SW|J4/2| |Reset | |P8/2|SC126 |
|SC126  |P5/1| |GND |TTL |2 |MCS-51M #1|
|SC126  |P5/2| |RTS | | | |
|SC126  |P5/3| |+5V |TTL |1 |MCS-51M #1|
|SC126  |P5/4| |RXD |TTL |4 |MCS-51M #1|
|SC126  |P5/5| |TXD |TTL |3 |MCS-51M #1|
|SC126  |P5/6| |CTS | | | |

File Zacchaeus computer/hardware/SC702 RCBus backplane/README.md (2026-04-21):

# Zacchaeus Microcomputer

## Hardware/SC702 RCBus backplane

### Directory content

|file |description |
|---|---|
|SC702.jpg |picture about assembled board |
|SC702 description.pdf |detailed description |
|SC702 kit contents.pdf |contents of the kit available for purchase|
|SC702 schematic.pdf |schematic drawing |
|SC702_v1.0.0_2023-03-21_00-15_Gerber.zip|Gerber files for manufacturing |

### About module

This is a commercially available backplane card with BP80 bus sockets designed
by Stephen C. Cousins. You can find the details in the original PDF files.

### Jumper settings

|Module|Num |Sign|Function |State |Note  |
|---|:--:|----|---|:---:|---|
|SC702 |JP1 | |connect P37 signal between bus sockets|1-2 closed |direct|
|SC702 |JP1 | |connect P38 signal between bus sockets|  4- | |
|SC702 |JP1 | |connect P39 signal between bus sockets|  6 closed | |
|SC702 |JP2 | |connect TX signal between bus sockets |1-2 closed |direct|
|SC702 |JP2 | |connect RX signal between bus sockets |3-4 closed |direct|
|SC702 |JP2 | |connect P37 signal between bus sockets|5-6 closed |direct|
|SC702 |JP2 | |connect P38 signal between bus sockets|  8- | |
|SC702 |JP2 | |connect P39 signal between bus sockets| 10 closed | |
|SC702 |JP3 | |connect P37 signal between bus sockets|1-2 closed |direct|
|SC702 |JP3 | |connect P38 signal between bus sockets|3-4 closed |direct|
|SC702 |JP3 | |connect P39 signal between bus sockets|5-6 closed |direct|
|SC702 |JP4 | |connect TX signal between bus sockets |1-2 closed |direct|
|SC702 |JP4 | |connect RX signal between bus sockets |3-4 closed |direct|
|SC702 |JP4 | |connect P37 signal between bus sockets|5-6 closed |direct|
|SC702 |JP4 | |connect P38 signal between bus sockets|7-8 closed |direct|
|SC702 |JP4 | |connect P39 signal between bus sockets|9-10 closed|direct|
|SC702 |JP5 | |connect P37 signal between bus sockets|1-2 closed |direct|
|SC702 |JP5 | |connect P38 signal between bus sockets|3-4 closed |direct|
|SC702 |JP5 | |connect P39 signal between bus sockets|5-6 closed |direct|
|SC702 |JP6 | |connect P42 signal between bus sockets|1-2 closed |direct|
|SC702 |JP6 | |connect P43 signal between bus sockets|3-4 closed |direct|
|SC702 |JP6 | |connect P44 signal between bus sockets|5-6 closed |direct|
|SC702 |JP7 | |connect P42 signal between bus sockets|1-2 closed |direct|
|SC702 |JP7 | |connect P43 signal between bus sockets|3-4 closed |direct|
|SC702 |JP7 | |connect P44 signal between bus sockets|5-6 closed |direct|
|SC702 |JP8 | |connect P42 signal between bus sockets|1-2 closed |direct|
|SC702 |JP8 | |connect P43 signal between bus sockets|3-4 closed |direct|
|SC702 |JP8 | |connect P44 signal between bus sockets|5-6 closed |direct|
|SC702 |JP9 | |connect P42 signal between bus sockets|1-2 closed |direct|
|SC702 |JP9 | |connect P43 signal between bus sockets|3-4 closed |direct|
|SC702 |JP9 | |connect P44 signal between bus sockets|5-6 closed |direct|
|SC702 |JP10| |connect P42 signal between bus sockets|1-2 closed |direct|
|SC702 |JP10| |connect P43 signal between bus sockets|3-4 closed |direct|
|SC702 |JP10| |connect P44 signal between bus sockets|5-6 closed |direct|

### Connection with others

The backplane does not connect to anything else except expansion cards.

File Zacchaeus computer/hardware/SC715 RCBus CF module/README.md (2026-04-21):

# Zacchaeus Microcomputer

## Hardware/SC715 RCBus CF module

### Directory content

|file |description |
|---|---|
|SC715.jpg |picture about assembled board |
|SC715 description.pdf |detailed description |
|SC715 kit contents.pdf |contents of the kit available for purchase|
|SC715 schematic.pdf |schematic drawing |
|SC715_v1.0.0_2023-04-27_14-17_Gerber.zip|Gerber files for manufacturing |

### About module

This is a commercially available expansion card designed by Stephen C. Cousins.
You can find the details in the original PDF files.

### Jumper settings

The CF module does not have jumpers.

### Connection with others

Only the CF adapter needs to be connected to the CF module, which requires its
own power supply (3.5" FDD power plug).

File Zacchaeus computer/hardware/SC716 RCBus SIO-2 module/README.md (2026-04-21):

# Zacchaeus Microcomputer

## Hardware/SC716 RCBus SIO-2 module

### Directory content

|file |description |
|---|---|
|SC716.jpg |picture about assembled board |
|SC716 description.pdf |detailed description |
|SC716 kit contents.pdf |contents of the kit available for purchase|
|SC716 schematic.pdf |schematic drawing |
|SC716_v1.0.0_2023-04-28_19-42_Gerber.zip|Gerber files for manufacturing |

### About module

This is a commercially available expansion card designed by Stephen C. Cousins.
You can find the details in the original PDF files.

### Jumper settings

|Module|Num |Sign|Function |State |Note|
|---|:--:|----|---|:---:|----|
|SC716 |JP1 |A7-0|I/O address |10000000  | |
|SC716 |JP2 | |clock source for port A (CLK2/X1 osc.)|2-3 closed| |
|SC716 |JP3 | |clock source for port B (CLK2/X1 osc.)|2-3 closed| |
|SC716 |JP4 | |connect bus TX to TXA/TXB |all opened| |
|SC716 |JP5 | |connect bus RX to RXA/RXB |all opened| |
|SC716 |JP6 | |connect bus TX2 to TXA/TXB |all opened| |
|SC716 |JP7 | |connect bus RX2 to RXA/RXB |all opened| |
|SC716 |JP8 |IEI |daisy-chain interrupt line |closed | |
|SC716 |JP9 |IEO |daisy-chain interrupt line |closed | |
|SC716 |JP10| |+5 V to serial connector A |opened | |
|SC716 |JP11| |+5 V to serial connector B |closed | |

### Connection with others

The serial ports of the card are connected to the male DB9 connectors on the
back panel according to the PBKP wiring diagram.

|Module |Num |Sign|Function|Sign|Num |Module |
|---|:--:|----|---|----|:--:|---|
|SC716  |P3/1| |GND |TTL |2 |MCS-51M #2|
|SC716  |P3/2| |RTS | | | |
|SC716  |P3/3| |+5V |TTL |1 |MCS-51M #2|
|SC726  |P3/4| |RXD |TTL |4 |MCS-51M #2|
|SC716  |P3/5| |TXD |TTL |3 |MCS-51M #2|
|SC716  |P3/6| |CTS | | | |

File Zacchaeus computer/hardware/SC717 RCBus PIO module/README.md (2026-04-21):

# Zacchaeus Microcomputer

## Hardware/SC717 RCBus PIO module

### Directory content

|file |description |
|---|---|
|SC717.jpg |picture about assembled board |
|SC717 description.pdf |detailed description |
|SC717 kit contents.pdf |contents of the kit available for purchase|
|SC717 schematic.pdf |schematic drawing |
|SC717_v1.0.0_2023-05-07_17-00_Gerber.zip|Gerber files for manufacturing |

### About module

This is a commercially available expansion card designed by Stephen C. Cousins.
You can find the details in the original PDF files.

### Jumper settings

|Module|Num|Sign|Function |State |Note|
|---|:-:|----|---|:---:|----|
|SC717 |JP1|A7-0|I/O address |01101000| |
|SC717 |JP2|IEI |daisy-chain interrupt line|closed  | |
|SC717 |JP3|IEO |daisy-chain interrupt line|closed  | |

### Connection with others

The paralel ports of the card are connected to the female DB25 connectors on the
back panel according to the PBKP wiring diagram.

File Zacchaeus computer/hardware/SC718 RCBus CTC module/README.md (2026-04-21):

# Zacchaeus Microcomputer

## Hardware/SC718 RCBus CTC module

### Directory content

|file |description |
|---|---|
|SC718.jpg |picture about assembled board |
|SC718 description.pdf |detailed description |
|SC718 kit contents.pdf |contents of the kit available for purchase|
|SC718 schematic.pdf |schematic drawing |
|SC718_v1.0.1_2023-05-26_16-41_Gerber.zip|Gerber files for manufacturing |

### About module

This is a commercially available expansion card designed by Stephen C. Cousins.
You can find the details in the original PDF files.

Channel 0 of the module is the user output on the back panel, channels 1-2 are
cascaded to provide the clock signal (CLK2 on bus) for the speaker interface,
and channel 3 is the timed interrupt.

### Jumper settings

|Module|Num |Sign |Function |State |Note|
|---|:----:|-----|---|:---:|----|
|SC718 |JP1 |A7-0 |I/O address |10001000| |
|SC718 |JP2 |CLK  |CTC0 clock source: system clock |closed  | |
| | |CLK2 |CTC0 clock source: CLK2 |opened  | |
| | |CLKX |CTC0 clock source: X1 oscillator|opened  | |
| | |INT1 |CTC0 clock source: INT1 |opened  | |
| | |INT2 |CTC0 clock source: INT2 |opened  | |
|SC718 |JP3 |CLK  |CTC1 clock source: system clock |closed  | |
| | |CLK2 |CTC1 clock source: CLK2 |opened  | |
| | |CLKX |CTC1 clock source: X1 oscillator|opened  | |
| | |INT1 |CTC1 clock source: INT1 |opened  | |
| | |INT2 |CTC1 clock source: INT2 |opened  | |
|SC718 |JP4 |CLK  |CTC2 clock source: system clock |opened  | |
| | |CLK2 |CTC2 clock source: CLK2 |opened  | |
| | |CLKX |CTC2 clock source: X1 oscillator|opened  | |
| | |INT1 |CTC2 clock source: INT1 |opened  | |
| | |INT2 |CTC2 clock source: INT2 |opened  | |
|SC718 |JP5 |CLK  |CTC3 clock source: system clock |closed  | |
| | |CLK2 |CTC3 clock source: CLK2 |opened  | |
| | |CLKX |CTC3 clock source: X1 oscillator|opened  | |
| | |INT1 |CTC3 clock source: INT1 |opened  | |
| | |ZT0  |CTC3 clock source: CTC2 output  |opened  | |
|SC718 |JP6 |ZT0  |CLK2 source: CTC0 output |closed  | |
| | |ZT1  |CLK2 source: CTC1 output |opened  | |
| | |ZT2  |CLK2 source: CTC2 output |closed  | |
| | |CLKX |CLK2 source: X1 oscillator |opened  | |
| | |CLX  |CLK2 source: system clock |opened  | |
|SC718 |JP7 |IEI  |daisy-chain interrupt line |closed  | |
|SC718 |JP8 |IEO  |daisy-chain interrupt line |closed  | |
|SC718 |JP9 |INT1 |interrupt line |opened  | |
|SC718 |JP10  |INT2 |interrupt line |opened  | |
|SC718 |P2/5-6|CTCIO|ZT1-CT2 cascade |closed  | |

### Connection with others

The first channel of the CTC module is connected to the DB9 connector on the
back panel. The wiring can be found in the PBKP wiring diagram.

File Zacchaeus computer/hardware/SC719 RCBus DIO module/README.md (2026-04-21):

# Zacchaeus Microcomputer

## Hardware/SC719 RCBus DIO module

### Directory content

|file |description |
|---|---|
|SC719.jpg |picture about assembled board |
|SC719 description.pdf |detailed description |
|SC719 kit contents.pdf |contents of the kit available for purchase|
|SC719 schematic.pdf |schematic drawing |
|SC719_v1.0.1_2023-05-26_16-24_Gerber.zip|Gerber files for manufacturing |

### About module

This is a commercially available expansion card designed by Stephen C. Cousins.
You can find the details in the original PDF files.

### Jumper settings

|Module|Num |Sign|Function |State |Note|
|---|:--:|----|---|:---:|----|
|SC719 |JP1 |A7-0|I/O address|00110000| |

### Connection with others

The DIO module is connected to the PIOI board. The wiring is in the PIOI's
README.md file.

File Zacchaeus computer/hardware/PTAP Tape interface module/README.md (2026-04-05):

# Zacchaeus Microcomputer

## Hardware/PTAP Tape and speaker interface module

### Directory content

|file |description |
|---|---|
|\[ptap\] |KiCAD files |
|KCS.md |Excerpts from the Kansas City Standard (1976)|
|ptap-B_Cu.pdf |solder side of the PCB |
|ptap-F_Cu.pdf |component side of the PCB |
|ptap-F_Silkscreen.pdf|silkscreen of the PCB |
|ptap-gerber.zip |Gerber files for manufacturing |
|ptap.jpg |module |
|ptap.pdf |schematic drawing |

### About module

This is a universal, MCU-based, BP-80 bus system-compatible expansion card
includes a flexibly configurable tape and speaker interfaces. The firmware
supports the FSK (Frequency-shift keying) modulation mode. The analog part of
the card can be used in the entire audio frequency band (20Hz-20 kHz). The data
transfer rate is 300-2400 baud, the frequency pairs can be between
600Hz-19.2 kHz. The module can be configured from the operating program. After
power-off or RESET, the default settings take effect. The module requires a +5 V
and a symmetrical 12 V power supply to operate.

#### Tape Interface

* **Data source:** Jumper-selectable between the serial port of the BP-80 bus
  or an external connector.
* **Modulation:** MCU's firmware supports the Kansas City Standard format, as
  well as the FSK mode using individual frequency pairs, which allows faster
  data transfer at higher tape speeds.
* **Output:** Harmonically filtered, sinusoidal signal, the level of which can
  be adjusted within limits with a trimmer potentiometer (mic/line level).
* **Input:** Automatically muted when not in use.
<<<<<<< HEAD
* **Control:** It has a built-in tape motor remote control and a mode indicator
  light output for the front panel LEDs.

### Speaker interface

* **Output:** TTL-level signal output and integrated transistor amplifier stage
  for driving low-impedance speakers.

### Jumper settings

All operating parameters of the card can be customized by jumpering.

|Module|Num |Sign  |Function |State |Note |
|---|:----:|:----:|---|:---:|---|
|PTAP  |SW1 |/A7-2 |I/O address |101011xx  |DIP switch, address 50h|
|PTAP  |JP1 |RXD0  |select RX line |1-2 closed|BP80/connector |
|PTAP  |JP2 |TXD0  |select TX line |1-2 closed|BP80/connector |
|PTAP  |JP3 | |mute speaker amplifier |opened | |
|PTAP  |JP4 | |enable speaker amplifier |closed | |

### Recording/Playback Parameters

The recording parameters are based on recommendations made at a symposium
held in Kansas City in 1975. (Kansas City Standard)

|medium  |tape speed|level L|cycle|level H |cycle|baudrate |bandwidth|note |
|---|---:|---:|:---:|---:|:---:|---:|---:|---|
|cassette| 4.76 cm/s|1200 Hz|  4  | 2400 Hz|  8  | 300 baud| ~3 kHz|original KCS|
|cassette| 4.76 cm/s|2400 Hz|  4  | 4800 Hz|  8  | 600 baud| ~5 kHz|maximal |
|tape | 2.38 cm/s| 600 Hz|  4  | 1200 Hz|  8  | 150 baud| ~2 kHz|suggested |
|tape | 4.76 cm/s|1200 Hz|  4  | 2400 Hz|  8  | 300 baud| ~3 kHz|suggested |
|tape | 9.53 cm/s|2400 Hz|  4  | 4800 Hz|  8  | 600 baud| ~5 kHz|suggested |
|tape |19.05 cm/s|4800 Hz|  4  | 9600 Hz|  8  |1200 baud|  ~10 kHz|suggested |
|tape | 2.38 cm/s|1200 Hz|  4  | 2400 Hz|  8  | 300 baud| ~3 kHz|maximal |
|tape | 4.76 cm/s|4800 Hz|  4  | 9600 Hz|  8  |1200 baud|  ~10 kHz|maximal |
|tape | 9.53 cm/s|4800 Hz|  4  | 9600 Hz|  8  |1200 baud|  ~10 kHz|maximal |
|tape |19.05 cm/s|9600 Hz|  4  |19200 Hz|  8  |2400 baud|  ~20 kHz|maximal |

The maximum valueswere calculated based on the parameters of the UHER 4000
tape recorder used.

### Connection with others

The module is connected to the BP80 expansion socket.

|Module|Num  |Sign|Function |Sign  |Num |Module|
|---|:---:|----|---|---|:--:|---|
|PTAP  |J1 | |expansion socket  | | |SC126 |
|PTAP  |J2 | |piezo speaker |TTL in|J3  |PSPK  |
|PTAP  |J3 | |dynamic speaker | | | |
|PTAP  |J4 |RLED|READ LED (green)  |RLED  |D3  |PFRP  |
|PTAP  |J5 |WLED|WRITE LED (red) |WLED  |D4  |PFRP  |
|PTAP  |J6 |MLED|MOTOR LED (yellow |MLED  |D5  |PFRP  |
|PPOW  | |+12V|+12V input |+12V|J7/1  |PCOX  |
|PPOW  | |GND |GND |GND |J7/2  |PCOX  |
|PPOW  | |-12V|-12V input |-12V|J7/3  |PCOX  |
|PTAP  |J8/1 |REL |tape connector |REL |J1/1|PFRP  |
| |J8/2 |DIN |tape connector |DIN |J1/4|PFRP  |
| |J8/3 |GND |tape connector |GND |J1/2|PFRP  |
| |J8/4 |DOUT|tape connector |DOUT  |J1/5|PFRP  |
| |J8/5 |REL |tape connector |REL |J1/3|PFRP  |

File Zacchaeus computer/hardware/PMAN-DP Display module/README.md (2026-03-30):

# Zacchaeus Microcomputer

## Hardware/PMAN-DP Display module

### Directory content

|file |description |
|---|---|
|\[pman-dp\] |KiCAD files |
|pman-dp-B_Cu.pdf |solder side of the PCB |
|pman-dp-F_Cu.pdf |component side of the PCB |
|pman-dp-F_Silkscreen.pdf|silkscreen of the PCB |
|pman-dp-gerber.zip |Gerber files for manufacturing|
|pman-dp-?.pdf |installed module |
|pman-dp.pdf |schematic drawing |

### About module

The PMAN-DP module is the component of the Manual control panel, which
contains eight hexadecimal LED displays connected in a matrix. The module
has four selection lines and 8-bit data input, to which the displays are
connected in pairs. The blanking input of the displays is common. The module
requires +5V DC to operate.

#### The installed module

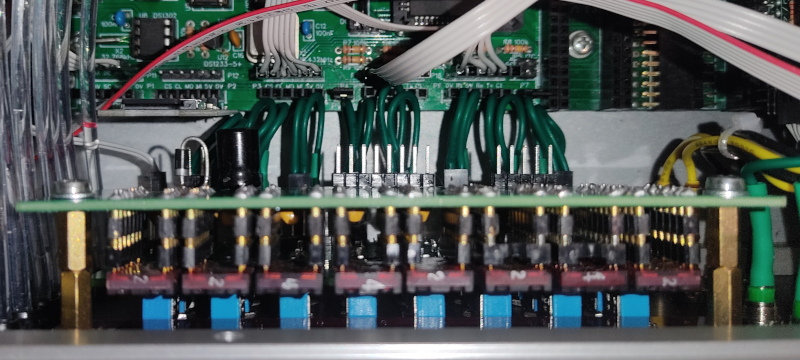
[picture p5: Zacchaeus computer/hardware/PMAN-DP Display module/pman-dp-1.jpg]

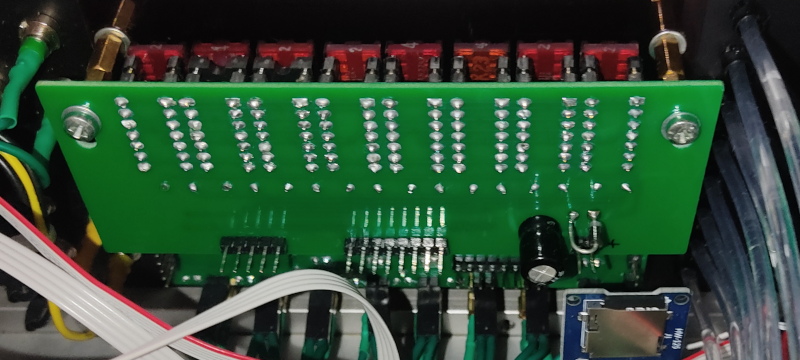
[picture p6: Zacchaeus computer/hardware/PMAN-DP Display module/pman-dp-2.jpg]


### Jumper settings

There is no jumper setting option on the module.

### Connection with others

This component is connected to the computer bus by the PMAN-IF interface module.

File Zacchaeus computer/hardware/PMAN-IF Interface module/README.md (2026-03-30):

# Zacchaeus Microcomputer

## Hardware/PMAN-IF interface module

### Directory content

|file |description |
|---|---|
|\[pman-if\] |KiCAD files |
|pman-if-B_Cu.pdf |solder side of the PCB |
|pman-if-F_Cu.pdf |component side of the PCB |
|pman-if-F_Silkscreen.pdf|silkscreen of the PCB |
|pman-if-gerber.zip |Gerber files for manufacturing|
|pman-if.jpg |module |
|pman-if.pdf |schematic drawing |

### About module

The PMAN-IF module is responsible for connecting the 8-digit hexadecimal
display, the switch and push-button matrix, and the status LEDs to the system
bus. The module requires +5V DC for operation.

### Jumper settings

|Module |Num |Sign |Function |State |Note |
|---|:--:|-----|---|:---:|---|
|PMAN-IF|SW1 |/A7-3|I/O address|0xx10111|DIP switch, address 40-47h|

### Connection with others

|Module |Num |Sign|Function |Sign|Num |Module |
|---|:--:|----|---|----|:--:|---|
|PMAN-IF|J4/1|+5V |+5V |+5V |J1/1|PMAN-DP|
|PMAN-IF|J4/2|GND |GND |GND |J1/2|PMAN-DP|
|PMAN-IF|J3/1| S0 |DIS1/5 selection | S0 |J2/1|PMAN-DP|
|PMAN-IF|J3/2| S1 |DIS2/6 selection | S1 |J2/2|PMAN-DP|
|PMAN-IF|J3/3| S2 |DIS3/7 selection | S2 |J2/3|PMAN-DP|
|PMAN-IF|J3/4| S3 |DIS4/8 selection | S3 |J2/4|PMAN-DP|
|PMAN-IF|J3/5| BL |DIS1-8 blank | BL |J2/5|PMAN-DP|
|PMAN-IF|J2/1| D0 |DIS1-4 data input A | D0 |J3/1|PMAN-DP|
|PMAN-IF|J2/2| D1 |DIS1-4 data input B | D1 |J3/2|PMAN-DP|
|PMAN-IF|J2/3| D2 |DIS1-4 data input C | D2 |J3/3|PMAN-DP|
|PMAN-IF|J2/4| D3 |DIS1-4 data input D | D3 |J3/4|PMAN-DP|
|PMAN-IF|J2/5| D4 |DIS5-8 data input A | D4 |J3/5|PMAN-DP|
|PMAN-IF|J2/6| D5 |DIS5-8 data input B | D5 |J3/6|PMAN-DP|
|PMAN-IF|J2/7| D6 |DIS5-8 data input C | D6 |J3/7|PMAN-DP|
|PMAN-IF|J2/8| D7 |DIS5-8 data input D | D7 |J3/8|PMAN-DP|
|PMAN-IF|J6/1| C0 |Column output | C0 |J1/1|PMAN-SW|
|PMAN-IF|J6/2| C1 |Column output | C1 |J1/2|PMAN-SW|
|PMAN-IF|J6/3| C2 |Column output | C2 |J1/3|PMAN-SW|
|PMAN-IF|J6/4| C3 |Column output | C3 |J1/4|PMAN-SW|
|PMAN-IF|J6/5| C4 |Column output | C4 |J1/5|PMAN-SW|
|PMAN-IF|J6/6| C5 |Column output | C5 |J1/6|PMAN-SW|
|PMAN-IF|J6/7| C6 |Column output | C6 |J1/7|PMAN-SW|
|PMAN-IF|J6/8| C7 |Column output | C7 |J1/8|PMAN-SW|
|PMAN-IF|J2/1| R0 |Row selection (A0-A7) | R0 |J2/1|PMAN-SW|
|PMAN-IF|J2/2| R1 |Row selection (A8-A15) | R1 |J2/2|PMAN-SW|
|PMAN-IF|J2/3| R2 |Row selection (D0-D7) | R2 |J2/3|PMAN-SW|
|PMAN-IF|J2/4| R3 |Row selection (buttons)  | R3 |J2/4|PMAN-SW|
|PMAN-IF|J8/1|GND |GND |GND |J4/1|PMAN-SW|
|PMAN-IF|J8/2| |NMI button | |J4/2|PMAN-SW|
|PMAN-IF|J7/1|GND |Common cathode |GND |J5/1|PMAN-SW|
|PMAN-IF|J7/2| |ERROR LED anode | |J5/2|PMAN-SW|
|PMAN-IF|J7/3| |RUN LED anode | |J5/3|PMAN-SW|
|PMAN-IF|J7/4| |PAUSE LED anode | |J5/4|PMAN-SW|
|PMAN-IF|J7/5| |STOP LED anode | |J5/5|PMAN-SW|

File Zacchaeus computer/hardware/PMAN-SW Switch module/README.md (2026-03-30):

# Zacchaeus Microcomputer

## Hardware/PMAN-SW Switch module

### Directory content

|file |description |
|---|---|
|\[pman-sw\] |KiCAD files |
|pman-sw-B_Cu.pdf |solder side of the PCB |
|pman-sw-F_Cu.pdf |component side of the PCB |
|pman-sw-F_Silkscreen.pdf|silkscreen of the PCB |
|pman-sw-gerber.zip |Gerber files for manufacturing|
|pman-sw.pdf |schematic drawing |

### About module

The PMAN-SW module is the component of the Manual control panel, which contains
32 switches, 8 pushbuttons and 4 LEDs. Switches and six pushbuttons connected in
a matrix. The module has four row selection lines and eight column output line.
The other components are connected separately. The module does not require power
voltage to operate.

### Jumper settings

There is no jumper setting option on the module.

### Connection with others

This component is connected to the computer bus by the PMAN-IF interface module.

|Module |Num |Sign|Function |Sign|Num |Module |
|---|:--:|----|---|----|:--:|---|
|PMAN-SW|J3/1|GND |GND |GND |P8/1|SC126  |
|PMAN-SW|J3/2| |RESET button | |P8/2|SC126  |

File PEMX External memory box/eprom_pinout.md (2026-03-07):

# External memory box

## Comparison of the pinout of usable EPROMs

| Pin |2764|27128|27256|27512|Diff.|
|-----|----|-----|-----|-----|:---:|
| 1|VPP |VPP  |VPP  |A15  |  !  |
| 2|A12 |A12  |A12  |A12  | |
| 3|A7  |A7 |A7 |A7 | |
| 4|A6  |A6 |A6 |A6 | |
| 5|A5  |A5 |A5 |A5 | |
| 6|A4  |A4 |A4 |A4 | |
| 7|A3  |A3 |A3 |A3 | |
| 8|A2  |A2 |A2 |A2 | |
| 9|A1  |A1 |A1 |A1 | |
| 10|A0  |A0 |A0 |A0 | |
| 11|D0  |D0 |D0 |D0 | |
| 12|D1  |D1 |D1 |D1 | |
| 13|D2  |D2 |D2 |D2 | |
| 14|GND |GND  |GND  |GND  | |
| 15|D3  |D3 |D3 |D3 | |
| 16|D4  |D4 |D4 |D4 | |
| 17|D5  |D5 |D5 |D5 | |
| 18|D6  |D6 |D6 |D6 | |
| 19|D7  |D7 |D7 |D7 | |
| 20|/CE |/CE  |/CE  |/CE  | |
| 21|A10 |A10  |A10  |A10  | |
| 22|/OE |/OE  |/OE  |/OE  | |
| 23|A11 |A11  |A11  |A11  | |
| 24|A9  |A9 |A9 |A9 | |
| 25|A8  |A8 |A8 |A8 | |
| 26|N.C.|A13  |A13  |A13  |  !  |
| 27|/PGM|A14  |A14  |A14  |  !  |
| 28|VCC |VCC  |VCC  |VCC  | |

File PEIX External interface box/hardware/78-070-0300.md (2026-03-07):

# External interface box

## 78-070-0300 power supply module

> [!NOTE]
> This document is an independent, reverse-engineered description of this module
> It is not affiliated with, endorsed by, or derived from official manufacturer
> documentation.

### About module

_There are no position numbers or other markings printed on the panel._  

The unit is responsible for generating the 5 V DC voltage required to
power the TTL circuits. It also has a low-current power supply output and
a signal connection point. These will be defined later.  

The module uses +24 V (3A) power supply.

### Jumper settings

There is no jumper setting option on the module.

### Connection with bus

|Pin|Function |card-bus|Own sign|Note |
|--:|---|:---:|:---:|---|
| 2a|unknown | | |2a-2b-3z are shorted|
| 4a|N.C. | | | |
| 6a|+5 V | | | |
| 8a|+5 V | | | |
|10a|+5 V | | | |
|12a|+5 V | | | |
|14a|+5 V | | | |
|16a|+5 V | | | |
|18a|+5 V | | | |
|20a|+5 V | | | |
|22a|+5 V | | | |
|24a|+5 V | | | |
|26a|+5 V | | | |
|28a|+5 V | | | |
|30a|+5 V | | | |
|32a|+5 V | | | |
| 2b|unknown | | |2a-2b-3z are shorted|
| 4b|N.C. | | | |
| 6b|+5 V | | | |
| 8b|+5 V | | | |
|10b|+5 V | | | |
|12b|+5 V | | | |
|14b|+5 V | | | |
|16b|+5 V | | | |
|18b|N.C. | | | |
|20b|GND | | | |
|22b|GND | | | |
|24b|GND | | | |
|26b|GND | | | |
|28b|GND | | | |
|30b|GND | | | |
|32b|GND | | | |
| 2z|unknown | | |2a-2b-3z are shorted|
| 4z|unknown | | |PG or RST? |
| 6z|GND | | | |
| 8z|GND | | | |
|10z|GND | | | |
|12z|GND | | | |
|14z|GND | | | |
|16z|GND | | | |
|18z|GND | | | |
|20z|GND | | | |
|22z|GND | | | |
|24z|GND | | | |
|26z|GND | | | |
|28z|GND | | | |
|30z|GND | | | |
|32z|GND | | | |

### Softwares

This module does not have its own software.

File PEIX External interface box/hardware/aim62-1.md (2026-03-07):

# External interface box

## AIM62.1 A/D converter sub-module

> [!NOTE]
> This document is an independent, reverse-engineered description of this module
> It is not affiliated with, endorsed by, or derived from official manufacturer
> documentation.

### About module

_There are no position numbers or other markings printed on the panel._  

(..)

### Integrated circuits important for control

Appearance

|Own sign|Type |Function |Work |Note|
|:---:|:---:|---|---|----|
| | | | | |

(..)

### Jumper settings

(..)

### Connection with analog board (only control)

|Con|Pin|Function |aqm-ebe |Own sign|Note |
|:-:|--:|---|:---:|:---:|---|
| | | | | | |

### Softwares

This module does not have its own software.

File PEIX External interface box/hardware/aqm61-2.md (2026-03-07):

# External interface box

## AQM61.2 D/A converter sub-module

> [!NOTE]
> This document is an independent, reverse-engineered description of this module
> It is not affiliated with, endorsed by, or derived from official manufacturer
> documentation.

### About module

_There are no position numbers or other markings printed on the panel._  

This circuit generates the analog output signal with a 12-bit dual D/A converter
IC. The output signal can be -10..+10 V. The sub-module is mounted on the analog
panel of the analog output module.

### Integrated circuits important for control

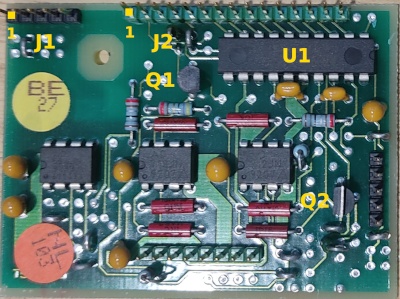
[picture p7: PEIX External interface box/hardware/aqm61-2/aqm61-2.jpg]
Appearance


|Own sign|Type |Function |Work |Note|
|:---:|:---:|---|---|----|
| U1 |AD7543JN|dual 12-bit D/A converter  |makes Vout| |
| U2 |AD584 |Precision voltage reference|makes Vref| |

Schematic in pdf: [aqm61-2.pdf](aqm61-2/aqm61-2.pdf)  

### Jumper settings

There is no jumper setting option on the module.

### Connection with analog board (only control)

|Con|Pin|Function |aqm-ebe |Own sign|Note |
|:-:|--:|---|:---:|:---:|---|
|J1 |  1|JP1 |  --->  | | |
|J1 |  2|JP2 |  --->  | |closed with common|
|J1 |  3|JP3 |  --->  | | |
|J1 |  4|JP4 |  --->  | | |
|J1 |  5|JPC |  <---  | | |
|J2 |  1|N.C. | | | |
|J2 |  2|CLR |  <---  | |U1/11 |
|J2 |  3|N.C. | | | |
|J2 |  4|ZRO |  <---  | |Q2/B U2/5 |
|J2 |  5|DB3 |  <---  | |Q1/B |
|J2 |  6|/WR |  <---  | |U1/10 |
|J2 |  7|/CS |  <---  | |U1/9 |
|J2 |  8|A0 |  <---  | |U1/8 |
|J2 |  9|A1 |  <---  | |U1/7 |
|J2 | 10|A2 |  <---  | |U1/6 |
|J2 | 11|/UPD |  <---  | |U1/5 |
|J2 | 12|DB0 |  <---  | |U1/4 |
|J2 | 13|DB1 |  <---  | |U1/3 |
|J2 | 14|DB2 |  <---  | |U1/2 |
|J2 | 15|DB3/E |  <---  | |Q1/E |

### Softwares

This module does not have its own software.

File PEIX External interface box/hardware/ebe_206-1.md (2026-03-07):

# External interface box

## EBE 206.1 digital input module

> [!NOTE]
> This document is an independent, reverse-engineered description of this module
> It is not affiliated with, endorsed by, or derived from official manufacturer
> documentation.

### About module

_There are no position numbers or other markings printed on the panel._  

The 16 inputs are isolated by optocouplers.

Reading the input channel status:

- setting the card address on lines DA0..5,
- setting the input channel number on lines DS0..3,
- reading the input channel status on lines DI.

The card uses internal +5 V power supply.

### Integrated circuits important for control

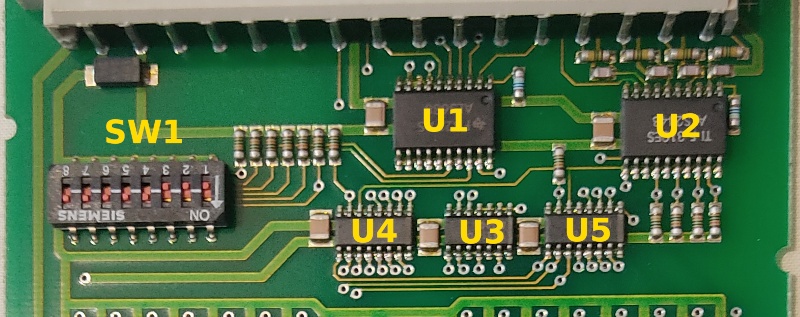
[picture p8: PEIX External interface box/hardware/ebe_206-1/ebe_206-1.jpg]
Appearance


|Own sign|Type |Function |Work |Note |
|:---:|:---:|---|---|---|
| U1 |74ALS688|8-bit identity comparator|card address comparison | |
| U2 |74ALS244|octal bus line driver |DSn and D0 lines drive  | |
| U3 |74ALS00 |quad 2-input NAND gate |gating multiplexers | |
| U4 |74HC251 |data selector/multiplexer|connect input line to DI|input 0-7 |
| U5 |74HC251 |data selector/multiplexer|connect input line to DI|input 8-16|

Schematic in pdf: [ebe_206-1.pdf](ebe_206-1/ebe_206-1.pdf)  

### Jumper settings

The card address can be set using the 8-position DIP switch (SW1).

|Num|Own sign|Function |Note|
|--:|:---:|---|----|
| 1 |'DA0 |card address| |
| 2 |'DA1 |card address| |
| 3 |'DA2 |card address| |
| 4 |'DA3 |card address| |
| 5 |'DA4 |card address| |
| 6 |'DA5 |card address| |
| 7 | |not used | |
| 8 | |not used | |

'DAn switches == DAn lines.

### Connection with bus

|Pin|Function |card-CPU|Own sign|Note |
|--:|---|:---:|:---:|---|
| 2a|GND | | | |
| 4a|+5 V | | | |
| 6a|N.C. | | | |
| 8a|N.C. | | | |
|10a|N.C. | | | |
|12a|input status |  --->  |  DI | |
|14a|card address line |  <---  |  DA5 | |
|16a|card address line |  <---  |  DA4 | |
|18a|card address line |  <---  |  DA3 | |
|20a|card address line |  <---  |  DA2 | |
|22a|card address line |  <---  |  DA1 | |
|24a|card address line |  <---  |  DA0 | |
|26a|part selector line|  <---  |  DS3 |L/H: DI0..7/DI8..15|
|28a|port selector line|  <---  |  DS2 | |
|30a|port selector line|  <---  |  DS1 | |
|32a|port selector line|  <---  |  DS0 | |

### Softwares

This module does not have its own software. Its operation was ensured by the
CPU module of the original system.

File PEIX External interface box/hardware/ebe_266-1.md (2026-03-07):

# External interface box

## EBE 266.1 digital output module

> [!NOTE]
> This document is an independent, reverse-engineered description of this module
> It is not affiliated with, endorsed by, or derived from official manufacturer
> documentation.

### About module

_There are no position numbers or other markings printed on the panel._  

The external voltage is switched to the 16 outputs by optocoupler-isolated
electronic switches. The status of the outputs can be reset from the bus and
with an external push button.

Setting the state of an output channel:

- setting the card address on lines DA0..5,
- setting the number of the output channel on lines DS0..3,
- setting the state of the  output channel on line D0
- setting /AEN low to write the state of D0 to the output buffer, then pulling
  it high again.

The card uses internal +5 V and external +24 V power supply.

### Integrated circuits important for control

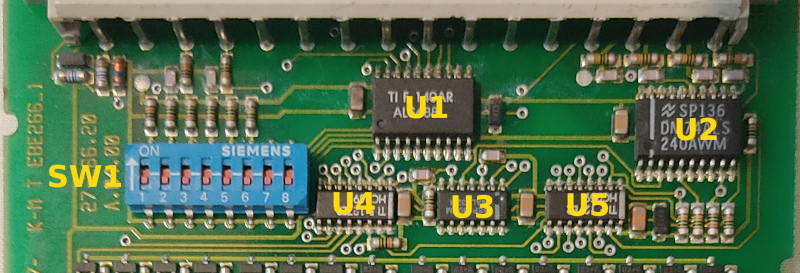
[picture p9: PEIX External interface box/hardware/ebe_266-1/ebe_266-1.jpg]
Appearance


|Own sign|Type |Function |Work |Note |
|:---:|:---:|---|---|---|
| U1 |74ALS688|8-bit identity comparator  |card address comparison | |
| U2 |74ALS240|octal inverting line driver|data line drive and invert| |
| U3 |74ALS32 |quad 2-input OR gate |gating latches | |
| U4 |74HC259 |8-bit addressable latches  |output data storage |output 0-7 |
| U5 |74HC259 |8-bit addressable latches  |output data storage |output 8-16|

Schematic in pdf: [ebe_266-1.pdf](ebe_266-1/ebe_266-1.pdf)  

### Jumper settings

The card address can be set using the 8-position DIP switch (SW1).

|Num|Own sign|Function |Note|
|--:|:---:|---|----|
| 1 |'DA0 |card address| |
| 2 |'DA1 |card address| |
| 3 |'DA2 |card address| |
| 4 |'DA3 |card address| |
| 5 |'DA4 |card address| |
| 6 |'DA5 |card address| |
| 7 | |not used | |
| 8 | |not used | |

'DAn switches == DAn lines.

### Connection with bus

|Pin|Function |card-CPU|Own sign|Note |
|--:|---|:---:|:---:|---|
| 2a|GND | | | |
| 4a|+5 V | | | |
| 6a|output status |  <---  |  D0 | |
| 8a|address enable |  <---  |  /AEN  | |
|10a|clear output latches|  <---  |  /RST  | |
|12a|N.C. | | | |
|14a|card address line |  <---  |  DA5 | |
|16a|card address line |  <---  |  DA4 | |
|18a|card address line |  <---  |  DA3 | |
|20a|card address line |  <---  |  DA2 | |
|22a|card address line |  <---  |  DA1 | |
|24a|card address line |  <---  |  DA0 | |
|26a|part selector line  |  <---  |  DS3 |L/H: DI0..7/DI8..15|
|28a|port selector line  |  <---  |  DS2 | |
|30a|port selector line  |  <---  |  DS1 | |
|32a|port selector line  |  <---  |  DS0 | |

### Softwares

This module does not have its own software. Its operation was ensured by the
CPU module of the original system.

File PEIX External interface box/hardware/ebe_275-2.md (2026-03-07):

# External interface box

## EBE 275.2 analog input module

> [!NOTE]
> This document is an independent, reverse-engineered description of this module
> It is not affiliated with, endorsed by, or derived from official manufacturer
> documentation.

### About module

_There are no position numbers or other markings printed on the panel._  

(..)

### Integrated circuits important for control

#### Digital board

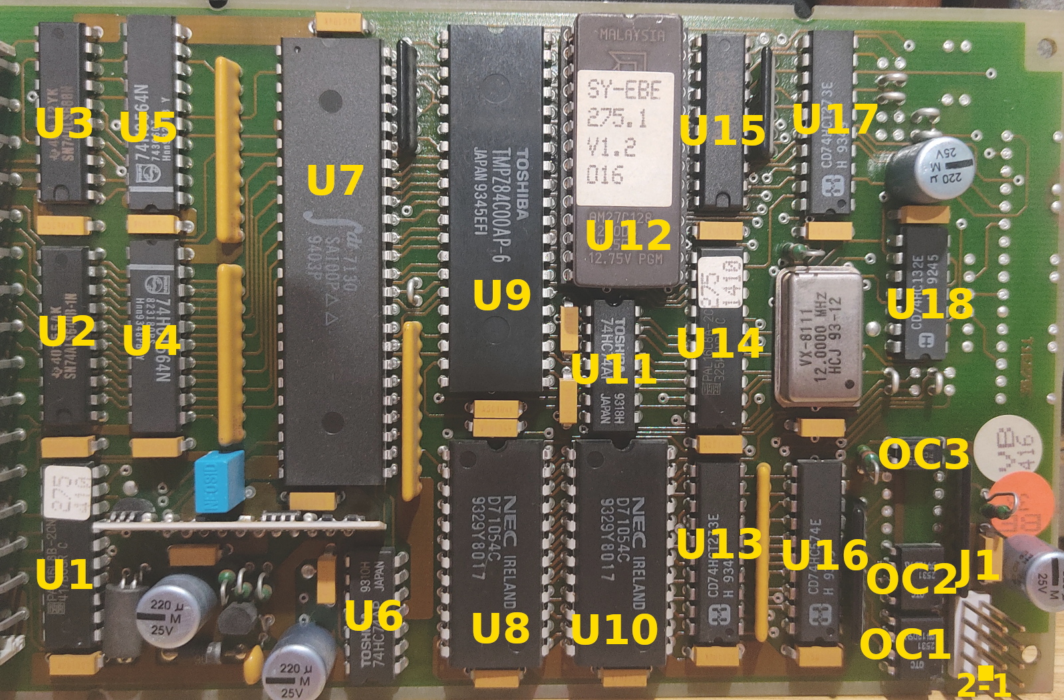
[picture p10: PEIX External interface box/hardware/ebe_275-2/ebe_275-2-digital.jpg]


|Own sign|Type |Function |Work |Note |
|:---:|:---:|---|---|---|
| | | | | |

(..)

#### Analog board

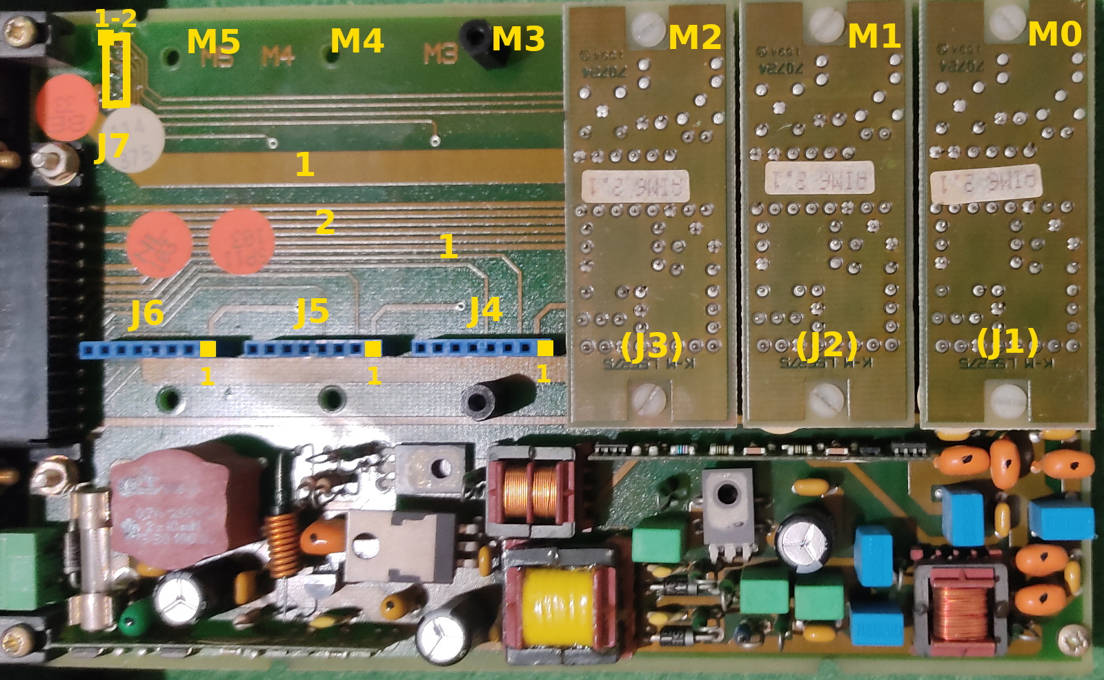
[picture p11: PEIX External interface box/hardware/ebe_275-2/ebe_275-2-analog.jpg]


(..)

### Jumper settings

(..)

### Connection with bus

|Pin|Function |card-CPU|Own sign|Note |
|--:|---|:---:|:---:|---|
| | | | | |

### Softwares

(..)

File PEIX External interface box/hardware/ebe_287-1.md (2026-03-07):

# External interface box

## EBE 287.1 analog output module

> [!NOTE]
> This document is an independent, reverse-engineered description of this module
> It is not affiliated with, endorsed by, or derived from official manufacturer
> documentation.

### About module

_There are no position numbers or other markings printed on the panel._  

The module consists of two main parts: the analog and the digital panel.

The analog panel has two additional components that determine the type of
output signal. The tested model has two AQM61.2 types, which can produce
-10..+10V in 12-bit resolution.

The digital board is a circuit built from traditional TTL and PAL circuits that controls the D/A converters on the analog board. The control of analog I/O
modules is completely different from that of digital ones.

(..)

The card uses internal +5V and external +24V power supply.

### Integrated circuits important for control

#### Digital board

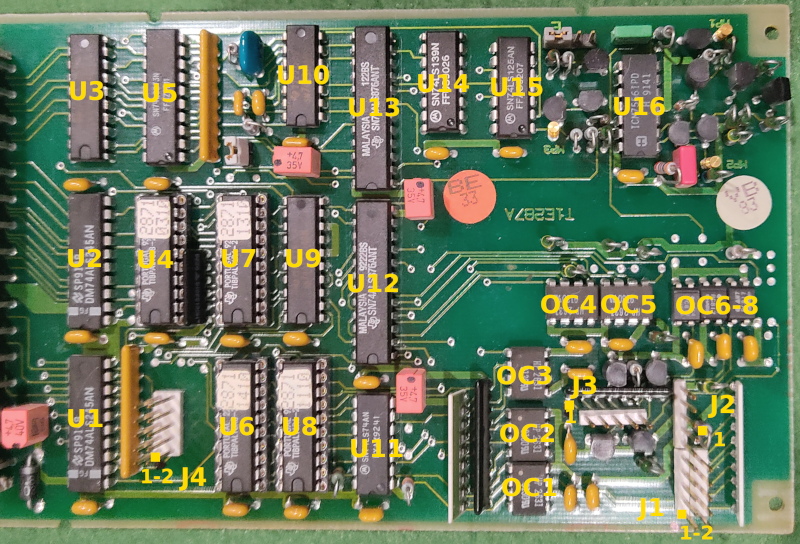
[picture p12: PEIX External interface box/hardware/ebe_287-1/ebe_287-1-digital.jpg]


|Own sign|Type |Function |Work |Note |
|:---:|:---:|---|---|---|
| U1 |74ALS245|bidirectional bus driver |read sub-modules' jumpers | |
| U2 |74ALS245|bidirectional bus driver |write address to storage  | |
| U3 |74ALS688|8-bit identity comparator  |card address comparison | |
| U4 |PAL16L8 |programmable array logic |unknown |2871 0310  |
| U5 |74LS273 |octal D-type Flip-flops |card address storage | |
| U6 |PAL16R8 |programmable array logic |unknown |2871 1410  |
| U7 |PAL16R4 |programmable array logic |unknown |2871 1310  |
| U8 |PAL16R6 |programmable array logic |unknown |2871 1110  |
| U9 |74ALS244|octal bus line driver | | |

(..)

Schematic in pdf: [ebe_287-1-digital.pdf](ebe_287-1/ebe_287-1-digital.pdf)  

#### Analog board

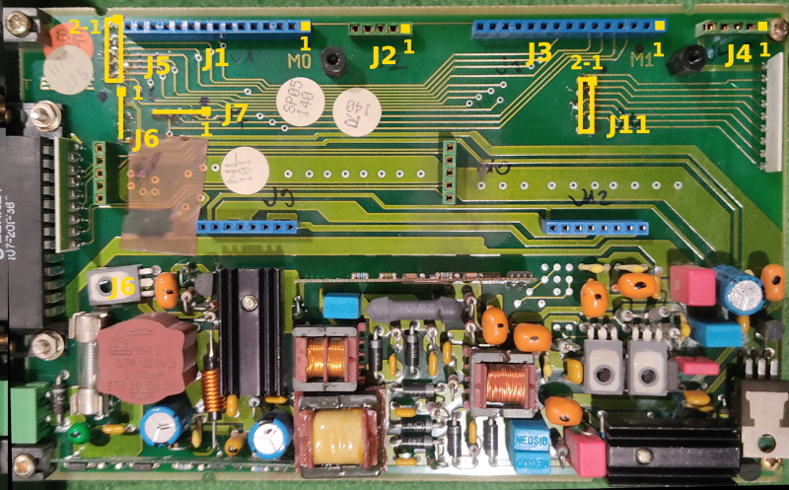
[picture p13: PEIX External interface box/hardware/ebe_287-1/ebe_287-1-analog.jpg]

(..)

Schematics in pdf:  

- [ebe_287-1-analog.pdf](ebe_287-1/ebe_287-1-analog.pdf)  
- [aqm61-2.pdf](aqm61-2/aqm61-2.pdf)  

### Jumper settings

(..)

### Connection with bus

|Pin|Function |card-CPU|Own sign|Note |
|--:|---|:---:|:---:|---|
| 2a|GND | | | |
| 4a|+5V | | | |
| 6a|N.C. | | | |
| 8a|N.C. | | | |
|10a|/RST |  <---  |  /RST  | |
|12a|N.C. | | | |
|14a|N.C. | | | |
|16a|N.C. | | | |
|18a|N.C. | | | |
|20a|N.C. | | | |
|22a|N.C. | | | |
|24a|N.C. | | | |
|26a|N.C. | | | |
|28a|N.C. | | | |
|30a|N.C. | | | |
|32a|N.C. | | | |
| 2b|N.C. | | | |
| 4b|N.C. | | | |
| 6b|N.C. | | | |
| 8b|N.C. | | | |
|10b|unknown |  <---  | | |
|12b|unknown |  --->  | | |
|14b|unknown |  <---  | | |
|16b|N.C. |  <---  | | |
|18b|data 0 |  <---  |  D0 | |
|20b|data 2 |  <---  |  D2 | |
|22b|data 4 |  <---  |  D4 | |
|24b|data 6 |  <---  |  D6 | |
|26b|card address line |  <---  |  DA0 | |
|28b|card address line |  <---  |  DA2 | |
|30b|card address line |  <---  |  DA4 | |
|32b|card address line |  <---  |  DA6 | |
| 2z|N.C. | | | |
| 4z|N.C. | | | |
| 6z|N.C. | | | |
| 8z|N.C. | | | |
|10z|unknown |  <---  | | |
|12z|unknown |  <---  | | |
|14z|GND | | | |
|16z|unknown |  <---  | | |
|18z|data line |  <---  |  D1 | |
|20z|data line |  <---  |  D3 | |
|22z|data line |  <---  |  D5 | |
|24z|data line |  <---  |  D7 | |
|26z|card address line |  <---  |  DA1 | |
|28z|card address line |  <---  |  DA3 | |
|30z|card address line |  <---  |  DA5 | |
|32z|card address line |  <---  |  DA7 | |

### Softwares

This module does not have its own software. Its operation was ensured by the
CPU module of the original system.

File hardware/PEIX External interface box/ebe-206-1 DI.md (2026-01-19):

# Zacchaeus Microcomputer

## EBE-206.1 digital input module

> [!NOTE]
> This document is an independent, reverse-engineered description of this module
> It is not affiliated with, endorsed by, or derived from official manufacturer
> documentation.
>

### About module

_There are no position numbers or other markings printed on the panel._  

The 16 inputs are isolated by optocouplers.

Reading the input channel status:
- setting the card address on lines DA0..5,
- setting the input channel number on lines DS0..3,
- reading the input channel status on lines D0.

The card uses internal +5V and external +24V power supply. 

### Integrated circuits important for control

<p align="center">
Appearance
</p>

|Own sign|Type |Function |Work |Note |
|:---:|:---:|---|---|---|
| U1 |74ALS688|8-bit identity comparator  |card address comparison | |
| U2 |74ALS244|octal bus line driver |DSn and D0 lines drive | |
| U3 |74ALS00 |quad 2-input NAND gate |gating multiplexers | |
| U4 |74HC251 |data selector/multiplexer  |connect input line to D0  |input 0-7  |
| U5 |74HC251 |data selector/multiplexer  |connect input line to D0  |input 8-16 |

Schematic in pdf: [ebe-206-1.pdf](ebe-206-1/ebe-206-1.pdf)  

### Jumper settings

The card address can be set using the 8-position DIP switch (SW1).

|Num|Own sign|Function |Note|
|--:|:---:|---|----|
| 1 |'DA0 |card address| |
| 2 |'DA1 |card address| |
| 3 |'DA2 |card address| |
| 4 |'DA3 |card address| |
| 5 |'DA4 |card address| |
| 6 |'DA5 |card address| |
| 7 | |not used | |
| 8 | |not used | |

'DAn switches == DAn lines.

### Connection with bus

|Pin|Function |card-CPU|Own sign|Note |
|--:|---|:---:|:---:|---|
| 2a|GND | | | |
| 4a|+5V | | | |
| 6a|N.C. | | | |
| 8a|N.C. | | | |
|10a|N.C. | | | |
|12a|input status |  --->  |  D0 | |
|14a|card address line |  <---  |  DA5 | |
|16a|card address line |  <---  |  DA4 | |
|18a|card address line |  <---  |  DA3 | |
|20a|card address line |  <---  |  DA2 | |
|22a|card address line |  <---  |  DA1 | |
|24a|card address line |  <---  |  DA0 | |
|26a|part selector line  |  <---  |  DS3 |L/H: DI0..7/DI8..15|
|28a|port selector line  |  <---  |  DS2 | |
|30a|port selector line  |  <---  |  DS1 | |
|32a|port selector line  |  <---  |  DS0 | |

### Softwares

This module does not have its own software. Its operation was ensured by the
CPU module of the original system.

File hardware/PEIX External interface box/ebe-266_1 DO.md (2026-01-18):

# Zacchaeus Microcomputer

## EBE-266.1 digital output module

> [!NOTE]
> This document is an independent, reverse-engineered description of this module
> It is not affiliated with, endorsed by, or derived from official manufacturer
> documentation.
>

### About module

_There are no position numbers or other markings printed on the panel._  

The external voltage is switched to the 16 outputs by optocoupler-isolated
electronic switches. If the card address on the card address lines and the DIP
switch match, the card sets the output specified on the DSn lines to match the
DO line. The status of the outputs can be reset from the bus and with an
external push button. The card uses internal +5V and external +24V power supply. 

### Integrated circuits important for control

Appearance
<br>&nbsp;

|Own sign|Type |Function |Work |Note |
|:---:|:---:|---|---|---|
| U1 |74ALS688|8-bit identity comparator  |card address comparison| |
| U2 |74ALS240|octal inverting line driver| | |
| U3 |74ALS32 |quad 2-input OR gate |other logic | |
| U4 |74HC259 |8-bit addressable latches  |output latches #1 |out 0-7 |
| U5 |74HC259 |8-bit addressable latches  |output latches #2 |out 8-16|

### Jumper settings

The card address can be set using the 8-position DIP switch (SW1).

|SW |Own sign|Function |Note|
|--:|:---:|---|----|
| 1 |'DA0 |card address| |
| 2 |'DA1 |card address| |
| 3 |'DA2 |card address| |
| 4 |'DA3 |card address| |
| 5 |'DA4 |card address| |
| 6 |'DA5 |card address| |
| 7 | |N.C. | |
| 8 | |N.C. | |

'DAn switches == DAn lines.

### Connection with bus

|Pin|Function |card-CPU|Own sign|Note |
|--:|---|:---:|:---:|---|
| 2a|GND | | | |
| 4a|+5V | | | |
| 6a|DOn status |  <---  |  D0 | |
| 8a|/card not selected  |  --->  |  /NS | |
|10a|/reset |  <---  |  /RES  | |
|12a|N.C. | | | |
|14a|card address line |  <---  |  DA5 | |
|16a|card address line |  <---  |  DA4 | |
|18a|card address line |  <---  |  DA3 | |
|20a|card address line |  <---  |  DA2 | |
|22a|card address line |  <---  |  DA1 | |
|24a|card address line |  <---  |  DA0 | |
|26a|select mux/demux |  <---  |  DS3 |L/H: DI0..7/DI8..15|
|28a|mux/demux selector A|  <---  |  DS0 | |
|30a|mux/demux selector B|  <---  |  DS1 | |
|32a|mux/demux selector C|  <---  |  DS2 | |

### Softwares

This module does not have its own software. Its operation was ensured by the
CPU module of the original system.

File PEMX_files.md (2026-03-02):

# External memory box

## Current file status

This list tracks the current status of the project units:
- [ ] – In-progress or still-changing file.
- [x] – Completed, stable, and tested file or module.

Items **_marked this way_** are directories managed as a single unit, as the files
within form a single entity (e.g., CAD drawings).

- [ ] **PEMX External memory box**  
  - [x] README.md  
  - [x]	eprom_pinout.md  
  - [x]	**hardware**  
    - [x] **_pemx_**  
    - [x] **_pemx-cables_**  
    - [x] **_pemx-reset_**  
    - [x] pemx-B_Cu.pdf  
    - [x] pemx-F_Cu.pdf  
    - [x] pemx-F_Silkscreen.pdf  
    - [x] pemx-gbr.zip  
    - [x] pemx.pdf  
    - [x] pemx-cables.pdf  
    - [x] pemx-reset.pdf  
  - [ ] **software**  
    - [ ] emxdump.com  _(soon)_  
    - [ ] emxdump.pas  _(soon)_  
    - [x] emxdump.txt  
    - [ ] emxload.com  
    - [ ] emxload.txt  
    - [ ] emxload.z80  
    - [x] **pemxapi**  
      - [x] build.sub  
      - [x] pemxapi.rel  
      - [x] pemxapi.txt  
      - [x] pemxapi.z80  
    - [ ] **pemxfunc**  
      - [ ] pemxfunc.pas  _(soon)_  
      - [x] pemxfunc.txt

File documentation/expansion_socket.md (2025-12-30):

# Zacchaeus Microcomputer

## BP80 extended bus

SC126 has 80-pin expansion sockets which are an extended RC2014 bus, known as
Backplane-80 (or BP80). This is an unofficial variant of the RC2014 Bus.

|Pin |Signal Name|Dir.|From-to |Pin |Signal Name|Dir.|From-to |
|---:|---|----|---|---:|---|----|---|
| 41 | n41 | |not yet assigned|  1 | A15 | <- |CPU-A15 |
| 42 | n42 | |not yet assigned|  2 | A14 | <- |CPU-A14 |
| 43 | n43 | |not yet assigned|  3 | A13 | <- |CPU-A13 |
| 44 | n44 | |not yet assigned|  4 | A12 | <- |CPU-A12 |
| 45 | n45 | |not yet assigned|  5 | A11 | <- |CPU-A11 |
| 46 | n46 | |not yet assigned|  6 | A10 | <- |CPU-A10 |
| 47 | n47 | |not yet assigned|  7 | A9 | <- |CPU-A9 |
| 48 | n48 | |not yet assigned|  8 | A8 | <- |CPU-A8 |
| 49 | A23 | |not used |  9 | A7 | <- |CPU-A7 |
| 50 | A22 | |not used | 10 | A6 | <- |CPU-A6 |
| 51 | A21 | |not used | 11 | A5 | <- |CPU-A5 |
| 52 | A20 | |not used | 12 | A4 | <- |CPU-A4 |
| 53 | A19 | <- |CPU-A19 | 13 | A3 | <- |CPU-A3 |
| 54 | A18 | <- |CPU-A18_Tout | 14 | A2 | <- |CPU-A2 |
| 55 | A17 | <- |CPU-A19 | 15 | A1 | <- |CPU-A1 |
| 56 | A16 | <- |CPU-A19 | 16 | A0 | <- |CPU-A0 |
| 57 | GND | -  |power supply | 17 | GND | -  |power supply |
| 58 | +5V | <- |power supply | 18 | +5V | <- |power supply |
| 59 | /RFSH | <- |CPU-/RFSH | 19 | /M1 | <- |/M1 |
| 60 | PAGE | |not used | 20 | /RESET | <- |reset circuit |
| 61 | CLK2 | |not used | 21 | CLK | <- |CPU-PHI |
| 62 | /BUSAK | <- |CPU-/BUSACK | 22 | /INT | -> |CPU-/INT0 |
| 63 | /HALT | <- |CPU-/HALT | 23 | /MREQ | <- |CPU-/MEMRQ |
| 64 | /BUSRQ | -> |CPU-/BUSREQ | 24 | /WR | <- |CPU-/WR |
| 65 | /WAIT | -> |CPU-/WAIT | 25 | /RD | <- |CPU-/RD |
| 66 | /NMI | |CPU-/NMI | 26 | /IORQ | <- |CPU-/IORQ |
| 67 | D8 | |not used | 27 | D0 | <->|CPU-D0 |
| 68 | D9 | |not used | 28 | D1 | <->|CPU-D1 |
| 69 | D10 | |not used | 29 | D2 | <->|CPU-D2 |
| 70 | D11 | |not used | 30 | D3 | <->|CPU-D3 |
| 71 | D12 | |not used | 31 | D4 | <->|CPU-D4 |
| 72 | D13 | |not used | 32 | D5 | <->|CPU-D5 |
| 73 | D14 | |not used | 33 | D6 | <->|CPU-D6 |
| 74 | D15 | |not used | 34 | D7 | <->|CPU-D7 |
| 75 | TX2 | <- |CPU-TXA1 | 35 | TX | <- |CPU-TXA0 |
| 76 | RX2 | -> |CPU-RXA1 | 36 | RX | -> |CPU-RXA0 |
| 77 | USER5 | |not used | 37 | USER1 | |not used |
| 78 | USER6 | |I2C SCL | 38 | USER2 | |not used |
| 79 | USER7 | |I2C SDA | 39 | USER3 | |not used |
| 80 | USER8 | |IEI | 40 | USER4 | |IEO |

## USERn lines

USERn lines are the "free-to-use" lines of the RC2014 bus system. They were
created to keep the system flexible and allow users to add features that are
not part of the standard according to their individual needs.

### On the motherboard

|Pin|Signal Name|SC126 |
|--:|---|---|
| 37|USER1 | |
| 38|USER2 | |
| 39|USER2 | |
| 40|USER4 |IEO |
| 77|USER5 | |
| 78|USER6 |I2C SCL[^1]|
| 79|USER7 |I2C SDA[^2]|
| 80|USER8 |IEI |

### Backplane

The SC-702 backplane forwards all lines straight with basic jumpering,
but if necessary, daisy-chain interrupt lines can be created using the
USER lines. For the drawing, see [bus_connection.pdf](bus_connection.pdf).

### Expansion cards

|Pin|Signal Name|SC715|SC716  |SC717  |SC718 |SC719|PCOX|
|--:|---|-----|---|---|---|-----|----|
| 37|USER1 | | | |/INT1[^8] | | |
| 38|USER2 | |IEI[^4]|IEI[^6]|IEI[^9] | | |
| 39|USER2 | |IEO[^5]|IEO[^7]|IEO[^10]  | | |
| 40|USER4 | | | | | | |
| 77|USER5 | | | |/INT2[^11]| | |
| 78|USER6 | | | | | | |
| 79|USER7 | | | | | | |
| 80|USER8 | | | | | | |

### Jumpering

[^1]: SC126 JP5 close 1-2
[^2]: SC126 JP5 close 3-4
[^4]: SC716 JP8 close 1-2
[^5]: SC716 JP9 close 1-2
[^6]: SC717 JP2 close 1-2
[^7]: SC717 JP3 close 1-2
[^8]: SC718 JP9 close 1-2
[^9]: SC718 JP8 close 1-2
[^10]: SC718 JP7 close 1-2
[^11]: SC718 JP10 close 1-2

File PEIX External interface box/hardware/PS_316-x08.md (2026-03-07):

# External interface box

## PS_316-x08 backplane

> [!NOTE]
> This document is an independent, reverse-engineered description of this module
> It is not affiliated with, endorsed by, or derived from official manufacturer
> documentation.

### About module

_There are no position numbers or other markings printed on the panel._  

(..)

### Jumper settings

(..)

### Connection with bus

(..)

### Softwares

This module does not have its own software.

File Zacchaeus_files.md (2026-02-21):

# Zacchaeus Microcomputer

## Current file status

This list tracks the current status of the project units:
- [ ] – In-progress or still-changing file.
- [x] – Completed, stable, and tested file or module.

Items **_marked this way_** are directories managed as a single unit, as the files
within form a single entity (e.g., CAD drawings, original files).

- [ ] **Zacchaeus computer**  
  - [x] README.md  
  - [ ]	**hardware**
    - [x] **Front panel**
      - [x] README.md
      - [x] z180cpu.cdr
      - [x] zacchaeus.cdr
      - [x] zacchaeus_z180.dxf
      - [x] zacchaeus_z180.jpg
      - [x] zacchaeus_z180.panel
    - [x] **MCS-51M RS232 level shifter module**
      - [x] MCS-51M assembled.jpg
      - [x] MCS-51M size.jpg
      - [x] README.md
    - [x] **PBKP Back panel**
      - [x] pbkp.pdf
      - [x] README.md
      - [x] **_pbkp_**
    - [x] **PCOX COVOX module**
      - [x] pcox-B_Cu.pdf
      - [x] pcox-F_Cu.pdf
      - [x] pcox-F_Silkscreen.pdf
      - [x] pcox-gbr.zip
      - [ ] pcox.jpg
      - [x] pcox.pdf
      - [x] README.md
      - [x] **_pcox_**
    - [x] **PFRP Front panel**
      - [x] pfrp.pdf
      - [x] README.md
      - [x] **_pfrp_**
    - [x] **PIOI IO Interface module**
      - [x] pioi-B_Cu.pdf
      - [x] pioi-F_Cu.pdf
      - [x] pioi-F_Silkscreen.pdf
      - [x] pioi-gbr.zip
      - [x] pioi.jpg
      - [x] pioi.pdf
      - [x] README.md
      - [x] **_pioi_**
    - [x] **PMAN-DP Display module**
      - [x] pman-dp-1.jpg
      - [x] pman-dp-2.jpg
      - [x] pman-dp-B_Cu.pdf
      - [x] pman-dp-F_Cu.pdf
      - [x] pman-dp-F_Silkscreen.pdf
      - [x] pman-dp-gerber.zip
      - [x] pman-dp.pdf
      - [x] README.md
      - [x] **_pman-dp_**
    - [x] **PMAN-SW Switch module**
      - [x] pman-sw-B_Cu.pdf
      - [x] pman-sw-F_Cu.pdf
      - [x] pman-sw-F_Silkscreen.pdf
      - [x] pman-sw-gerber.zip
      - [x] pman-sw.pdf
      - [x] README.md
      - [x] **_pman-sw_**
    - [x] **PPOW Power distribution module**
      - [x] ppow-B_Cu.pdf
      - [x] ppow-F_Cu.pdf
      - [x] ppow-F_Silkscreen.pdf
      - [x] ppow-gerber.zip
      - [x] ppow.jpg
      - [x] ppow.pdf
      - [x] README.md
      - [x] **_ppow_**
    - [x] **PSPK Speaker amplifier module**
      - [x] pspk-B_Cu.pdf
      - [x] pspk-F_Silkscreen.pdf
      - [x] pspk-gerber.zip
      - [x] pspk.jpg
      - [x] pspk.pdf
      - [x] README.md
      - [x] **_pspk_**
    - [ ] **PTAP Tape interface module**
      - [x] KCS.md
      - [ ] ptap-B_Cu.pdf
      - [ ] ptap-F_Cu.pdf
      - [ ] ptap-F_Silkscreen.pdf
      - [ ] ptap-gbr.zip
      - [ ] ptap.jpg
      - [ ] ptap.pdf
      - [ ] README.md
    - [x] **RCBus**
      - [x] bus_connection.pdf
      - [x] bus_connection.zip
      - [x] RCBus* (original files)
    - [x] **SC126 Z180 motherboard**
      - [x] README.md
      - [x] SC126* (original files)
    - [x] **SC702 RCBus backplane**
      - [x] README.md
      - [x] SC702* (original files)
    - [x] **SC715 RCBus CF module**
      - [x] README.md
      - [x] SC715* (original files)
    - [x] **SC716 RCBus SIO-2 module**
      - [x] README.md
      - [x] SC716* (original files)
    - [x] **SC717 RCBus PIO module**
      - [x] README.md
      - [x] SC717* (original files)
    - [x] **SC718 RCBus CTC module**
      - [x] README.md
      - [x] SC718* (original files)
    - [x] **SC719 RCBus DIO module**
      - [x] README.md
      - [x] SC719* (original files)
  - [ ] **software**  
    - [ ] **PCOX COVOX module**
      - [ ] coxpiano.com
      - [ ] coxpiano.pas
      - [ ] coxpiano.txt
      - [ ] coxplayer.com
      - [ ] coxplayer.pas
      - [ ] coxplayer.txt
      - [ ] **pcoxapi**
        - [ ] build.sub
        - [ ] pcoxapi.rel
        - [ ] pcoxapi.txt
        - [ ] pcoxapi.z80
      - [ ] **pcoxfunc**
        - [ ] pcoxfunc.pas
        - [ ] pcoxfunc.txt
    - [x] **PIOI IO Interface module**
      - [x] pioitest.com
      - [x] pioitest.txt
      - [x] pioitest.z80
      - [x] **pioiapi**
        - [x] build.sub
        - [x] pioiapi.rel
        - [x] pioiapi.txt
        - [x] pioiapi.z80
        - [x] pioirst.com
        - [x] pioirst.z80
      - [x] **piofunc**
        - [x] pioifgen.pas
        - [x] pioifoco.pas
        - [x] pioifpi.pas
        - [x] pioifrco.pas
        - [x] pioifunc.txt
        - [x] pioirst.com
        - [x] pioirst.pas
    - [ ] **PTAP Tape interface module**
      - [ ] tapdump.com
      - [ ] tapdump.txt
      - [ ] tapdump.z80
      - [ ] tapload.com
      - [ ] tapload.txt
      - [ ] tapload.z80
      - [ ] tapsave.com
      - [ ] tapsave.txt
      - [ ] tapsave.z80
      - [ ] **ptapapi**
        - [ ] build.sub
        - [ ] ptapapi.rel
        - [ ] ptapapi.txt
        - [ ] ptapapi.z80
      - [ ] **ptapfunc**
        - [ ] ptapfunc.pas
        - [ ] ptapfunc.txt
    - [x] **_SC126 Z180 motherboard_** (original files)

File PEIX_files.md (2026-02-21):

# External interface box

## Current file status

This list tracks the current status of the project units:
- [ ] – In-progress or still-changing file.
- [x] – Completed, stable, and tested file or module.

Items **_marked this way_** are directories managed as a single unit, as the files
within form a single entity (e.g., CAD drawings).

- [ ] **PEIX External interface box**  
  - [x] README.md  
  - [ ] **hardware**  
    - [ ] 78-070-0300.md
    - [ ] aim62-1.md
    - [x] aqm61-2.md
    - [x] ebe_206-1.md
    - [x] ebe_266-1.md
    - [ ] ebe_275-2.md
    - [ ] ebe_287-1.md
    - [x] peix-B_Cu.pdf
    - [x] peix-F_Cu.pdf
    - [x] peix-F_Silkscreen.pdf
    - [x] peix-gbr.zip
    - [x] peix.pdf
    - [ ] PS_316-x08.md
    - [x] **aim62-1**  
      - [x] aim62-1.jpg
      - [ ] aim62-1.pdf
    - [x] **aqm61-2**  
      - [x] aqm61-2.jpg
      - [ ] aqm61-2.pdf
      - [x] **_aqm61-2_**  
    - [x] **ebe_206-1**  
      - [x] ebe_206-1.jpg
      - [x] ebe_206-1.pdf
      - [x] **_ebe_206-1_**
    - [x] **ebe_266-1**  
      - [x] ebe_266-1.jpg
      - [x] ebe_266-1.pdf
      - [x] **_ebe_266-1_**
    - [ ] **ebe_275-2**  
      - [x] ebe_275-2-analog.jpg
      - [ ] ebe_275-2-analog.pdf
    - [x] **ebe_287-1**  
      - [x] ebe_287-1/ebe_287-1-analog.jpg
      - [x] ebe_287-1/ebe_287-1-analog.jpg
      - [x] ebe_287-1/ebe_287-1-digital.pdf
      - [x] ebe_287-1/ebe_287-1-digital.pdf
      - [x] **_ebe_287-1_**
    - [x] **_peix_**  
    - [ ] **PS_316-x08**
      - [x] PS_316-x08.jpg
  - [ ] **software**  
    - [ ] eixmon.com
    - [ ] eixmon.txt
    - [ ] eixmon.pas
    - [ ] **firmware**  
      - [ ] peix-fw.asm
      - [ ] peix-fw.bin
      - [ ] peix-fw.txt
    - [ ] **peixapi**  
      - [x] build.sub  
      - [ ] peixapi.rel  
      - [ ] peixapi.txt  
      - [ ] peixapi.z80  
    - [ ] **pemxfunc**  
      - [ ] peixfunc.pas
      - [ ] peixfunc.txt

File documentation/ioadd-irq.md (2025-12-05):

# Zacchaeus Microcomputer

## I/O address table

|From|To  |Module|Function |Note |
|---:|---:|---|---|---|
|0x00|0x0A| | | |
| |0x0B|SC719 |MM8D module’s ports | |
| |0x0C|SC126 |System I/O port (RTC, SPI and I2C)|default  |
| |0x0D|SC126 |LED output port |default  |
|0x0E|0x0F| | | |
|0x10|0x17|SC715 |CF card |default  |
|0x18|0x6A| | | |
| |0x6B|SC717 |Z80 PIO’s internal I/O registers  |suggested|
|0x6C|0x7F| | | |
|0x80|0x83|SC716 |Z80 SIO/2’s internal I/O registers|suggested|
|0x84|0x8A| | | |
| |0x8B|SC718 |Z80 CTC’s internal I/O registers  |suggested|
|0x8C|0xBF| | | |
|0xC0|0xFF|SC126 |Z180’s internal I/O registers | default |

## IRQ table

|Number|Module|Function |Note |
|:----:|---|---|---|
|NMI | | | |
|INT1  | | | |
|INT2  | | | |
|INT3  | | | |
|INT4  | | | |

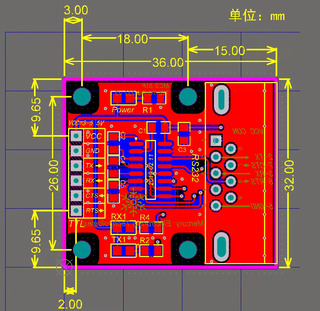
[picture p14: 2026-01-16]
Zacchaeus computer/hardware/MCS-51M RS232 level shifter module/MCS-51M size.jpg

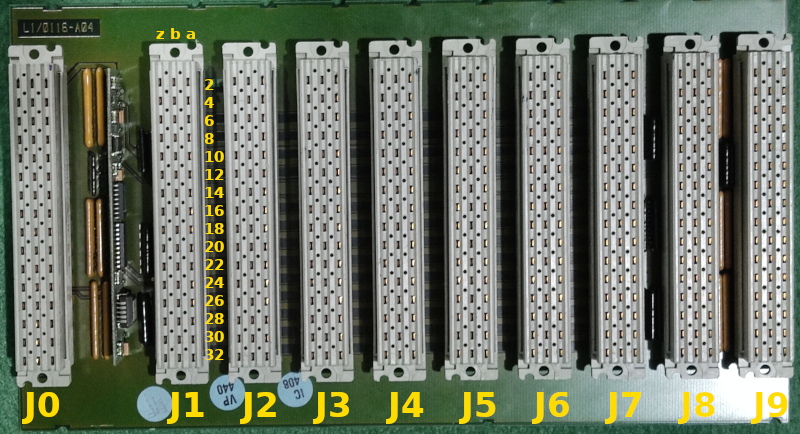
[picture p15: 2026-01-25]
PEIX External interface box/hardware/PS_316-x08/PS_316-x08.jpg

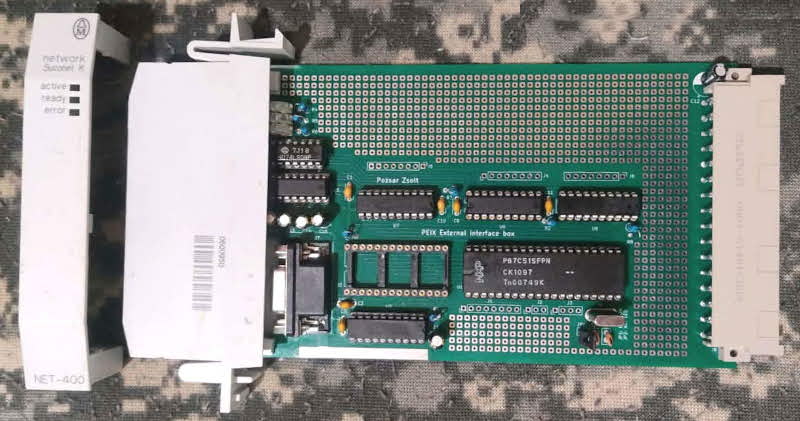
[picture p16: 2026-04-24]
PEIX External interface box/hardware/peix.jpg

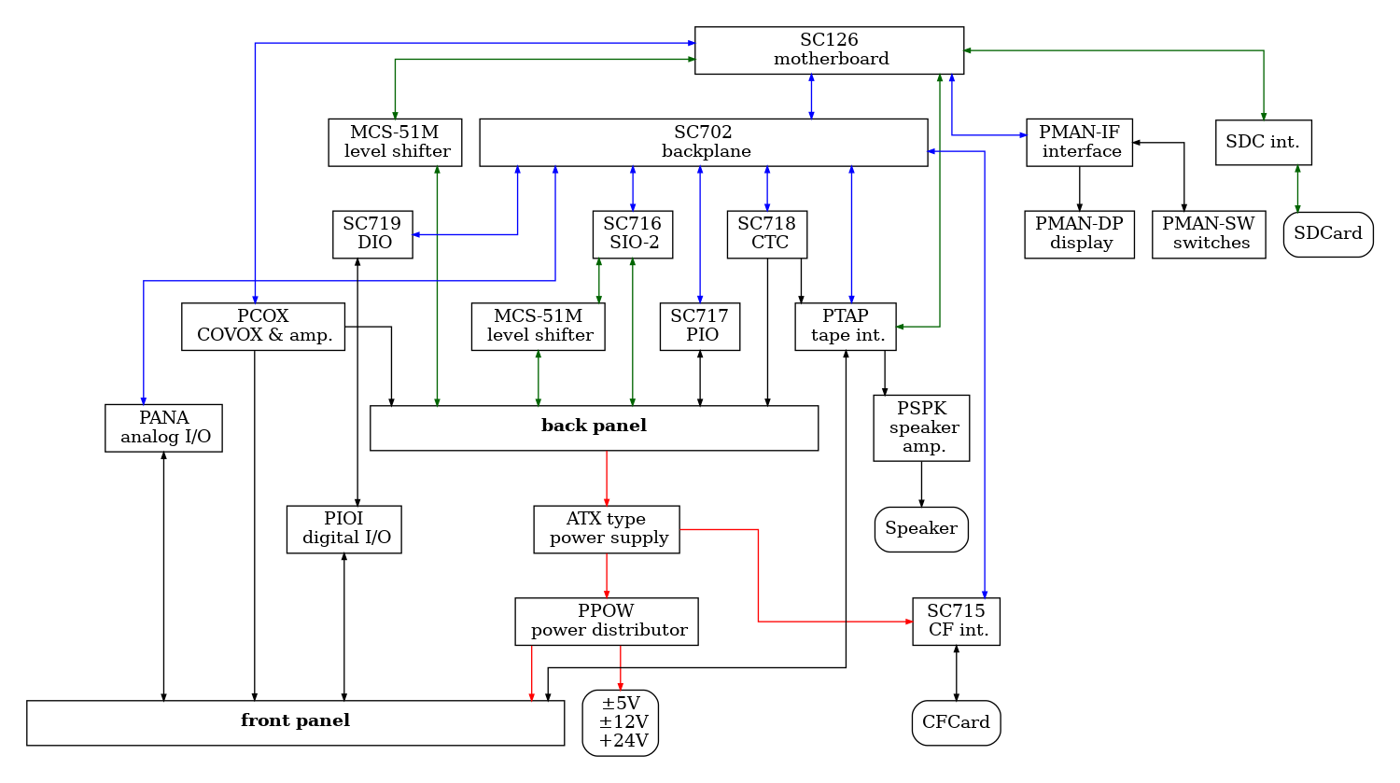
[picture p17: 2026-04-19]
Zacchaeus computer/hardware/Block diagram/blk_zacchaeus.png

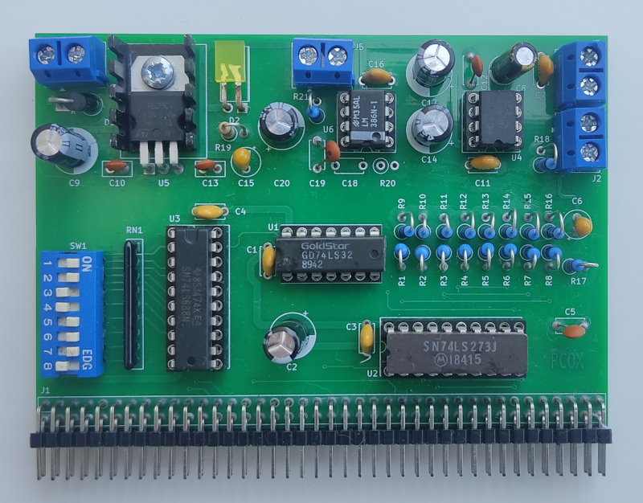
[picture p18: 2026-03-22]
Zacchaeus computer/hardware/PCOX COVOX module/pcox.jpg

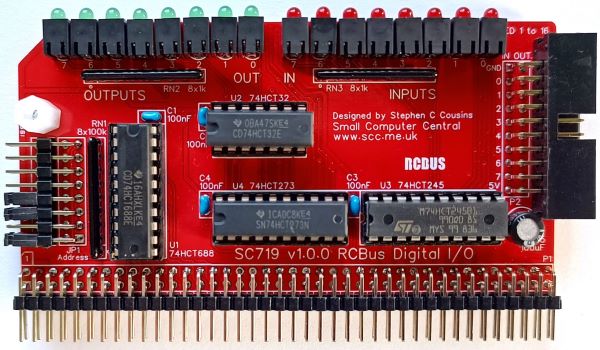
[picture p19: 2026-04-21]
Zacchaeus computer/hardware/SC719 RCBus DIO module/sc719.jpg

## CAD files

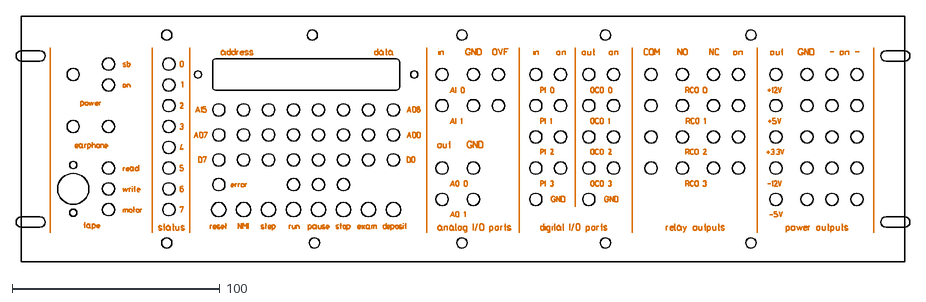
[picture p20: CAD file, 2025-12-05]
Zacchaeus computer/hardware/Front panel/zacchaeus_z180.dxf
430.0 x 118.0

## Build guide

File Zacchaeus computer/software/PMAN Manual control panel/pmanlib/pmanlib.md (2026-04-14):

# Zacchaeus Microcomputer

## PMAN routine collection

|Key |Value |
|---|---|
|version |v0.1 |
|licence |EUPL v1.2 |
|architecture|Z80 |
|OS |CP/M-80 |
|compiler |SLR Systems Z80ASM v1.32 (1986) |
|author |[Pozsar Zsolt](mailto:pozsarzs@gmail.com) (2026)  |
|web |[Pozsi's homepage](https://www.pozsarzs.hu) |
| |[on Github](https://github.com/pozsarzs/zacchaeus)|

This is a collection of routines for easy management of the manual control
panel's buttons, switches, LEDs and hexadecimal LED displays.

### Available functions

|A  |B |C |HL |Function|Return A|Return HL|
|:-:|:---:|:---:|:---:|---|:---:|:---|
|00h|ioaddr  | |bufaddr |IFINIT  | | |
|01h|on/off  | | |DPBLNK  | | |
|02h| | | |DPZERO  | | |
|03h|databyte| |dataword|DPWAAD  | | |
|04h|databyte| | |DPWBYB  | | |
|05h|databyte|stpos| |DPWBYH  | | |
|06h| |stpos|dataword|DPWWRD  | | |
|07h|number  |digit| |DPWDIG  | | |
|08h| | | |DPWMIR  | | |
|09h| | | |SWRADD  | |dataword |
|0Ah| | | |SWRDAT  |databyte| |
|0Bh| | | |SWRBTN  |databyte| |
|0Ch| | | |SWRMIR  | | |
|0Dh|databyte| | |SWWLED  | | |

**Notes:**  
  - _bufaddr.:_ address of the buffer area [00..FFh]
  - _databyte:_ data byte [00..FFh]
  - _dataword:_ data word [0000..FFFFh]
  - _digit:_ number of the display digit [0..7]
  - _ioaddr:_ base i/o address (BA) of interface [00..FFh]
  - _number:_ single digit number [0..F]
  - _stpos:_ start position, byte: [1..7], word: [3..7]

### Buffer map

|offset| bit7  | bit6  | bit5  | bit4  | bit3  | bit2  | bit1  | bit0  |
|---|:-----:|:-----:|:-----:|:-----:|:-----:|:-----:|:-----:|:-----:|
| 0  |DIG7-b7|DIG7-b6|DIG7-b5|DIG7-b4|DIG7-b3|DIG7-b2|DIG7-b1|DIG7-b0|
| 1  |DIG6-b7|DIG6-b6|DIG6-b5|DIG6-b4|DIG6-b3|DIG6-b2|DIG6-b1|DIG6-b0|
| 2  |DIG5-b7|DIG5-b6|DIG5-b5|DIG5-b4|DIG5-b3|DIG5-b2|DIG5-b1|DIG5-b0|
| 3  |DIG4-b7|DIG4-b6|DIG4-b5|DIG4-b4|DIG4-b3|DIG4-b2|DIG4-b1|DIG4-b0|
| 4  |DIG3-b7|DIG3-b6|DIG3-b5|DIG3-b4|DIG3-b3|DIG3-b2|DIG3-b1|DIG3-b0|
| 5  |DIG2-b7|DIG2-b6|DIG2-b5|DIG2-b4|DIG2-b3|DIG2-b2|DIG2-b1|DIG2-b0|
| 6  |DIG1-b7|DIG1-b6|DIG1-b5|DIG1-b4|DIG1-b3|DIG1-b2|DIG1-b1|DIG1-b0|
| 7  |DIG0-b7|DIG0-b6|DIG0-b5|DIG0-b4|DIG0-b3|DIG0-b2|DIG0-b1|DIG0-b0|
| 8  |  A15  |  A14  |  A13  |  A12  |  A11  |  A10  |  A09  |  A08  |
| 9  |  A07  |  A06  |  A05  |  A04  |  A03  |  A02  |  A01  |  A00  |
|  10  |  D7 |  D6 |  D5 |  D4 |  D3 |  D2 |  D1 |  D0 |
|  11  | 0 | 0 | STEP  |  RUN  | PAUS  | STOP  | EXAM  | DEPO  |
|  12  | 0 | 0 | 0 | BLANK | LERR  | LRUN  | LPAU  | LSTP  |

The first eight bytes of the buffer contain the display (DIG7..DIG0), the next
4 byte contain the position of the address switches (A15-A08) and the data
switches (D7-D0) and status of the pushbutton row. Last byte contains the LED
status. (1 is means closed switch or active LED.)

### Hardware access

#### Hexadecimal display on display module

|_on the board_|DIS1|DIS2|DIS3|DIS4|DIS5|DIS6|DIS7|DIS8|
|---|:--:|:--:|:--:|:--:|:--:|:--:|:--:|:--:|
|_logical name_|DIG7|DIG6|DIG5|DIG4|DIG3|DIG2|DIG1|DIG0|
|_i/o address_ |BA+3|BA+2|BA+1|BA  |BA+3|BA+2|BA+1|BA  |
|_nibble_ |low |low |low |low |high|high|high|high|

**Note:**
 - The display blanking signal (BLANK) is the 4th bit of the data written to
   i/o address BA + 4.

#### LEDs on switch module

|_on the board_|D31 |D32 |D33 |D34 |
|---|:--:|:--:|:--:|:--:|
|_logical name_|LERR|LRUN|LPAU|LSTP|
|_i/o address_ |BA+4|BA+4|BA+4|BA+4|
|_bit_ | 3  | 2  | 1  | 0  |

#### Switches on switch module

|_on the board_ |operation|SW1 |SW2 |SW3 |SW4 |SW5 |SW6 |SW7 |SW8 |
|---|:---:|:--:|:--:|:--:|:--:|:--:|:--:|:--:|:--:|
|_logical name_ | |A15 |A14 |A13 |A12 |A11 |A10 |A09 |A08 |
|_i/o address_ |select |BA+5|BA+5|BA+5|BA+5|BA+5|BA+5|BA+5|BA+5|
|_data_ |select |08h |04h |02h |01h |80h |40h |20h |10h |
|_i/o address_ |read |BA+6|BA+6|BA+6|BA+6|BA+6|BA+6|BA+6|BA+6|
|_bit_ (active low)| | 0  | 0  | 0  | 0  | 0  | 0  | 0  | 0  |

|_on the board_ |operation|SW9 |SW10|SW11|SW12|SW13|SW14|S15 |SW16|
|---|:---:|:--:|:--:|:--:|:--:|:--:|:--:|:--:|:--:|
|_logical name_ | |A07 |A06 |A05 |A04 |A03 |A02 |A01 |A00 |
|_i/o address_ |select |BA+5|BA+5|BA+5|BA+5|BA+5|BA+5|BA+5|BA+5|
|_data_ |select |08h |04h |02h |01h |80h |40h |20h |10h |
|_i/o address_ |read |BA+6|BA+6|BA+6|BA+6|BA+6|BA+6|BA+6|BA+6|
|_bit_ (active low)| | 1  | 1  | 1  | 1  | 1  | 1  | 1  | 1  |

|_on the board_ |operation|SW17|SW18|SW19|SW20|SW21|SW22|SW23|SW24|
|---|:---:|:--:|:--:|:--:|:--:|:--:|:--:|:--:|:--:|
|_logical name_ | | D7 | D6 | D5 | D4 | D3 | D2 | D1 | D0 |
|_i/o address_ |select |BA+5|BA+5|BA+5|BA+5|BA+5|BA+5|BA+5|BA+5|
|_data_ |select |08h |04h |02h |01h |80h |40h |20h |10h |
|_i/o address_ |read |BA+6|BA+6|BA+6|BA+6|BA+6|BA+6|BA+6|BA+6|
|_bit_ (active low)| | 2  | 2  | 2  | 2  | 2  | 2  | 2  | 2  |

|_on the board_ |operation|SW25|SW26|SW27|SW28|SW29|SW30|SW31|SW32|
|---|:---:|:--:|:--:|:--:|:--:|:--:|:--:|:--:|:--:|
|_logical name_ | |RST |NMI |STEP|RUN |PAUS|STOP|EXAM|DEPO|
|_i/o address_ |select | | |BA+5|BA+5|BA+5|BA+5|BA+5|BA+5|
|_data_ |select | | |02h |01h |80h |40h |20h |10h |
|_i/o address_ |read | | |BA+6|BA+6|BA+6|BA+6|BA+6|BA+6|
|_bit_ (active low)| | 3  | 3  | 3  | 3  | 3  | 3  | 3  | 3  |

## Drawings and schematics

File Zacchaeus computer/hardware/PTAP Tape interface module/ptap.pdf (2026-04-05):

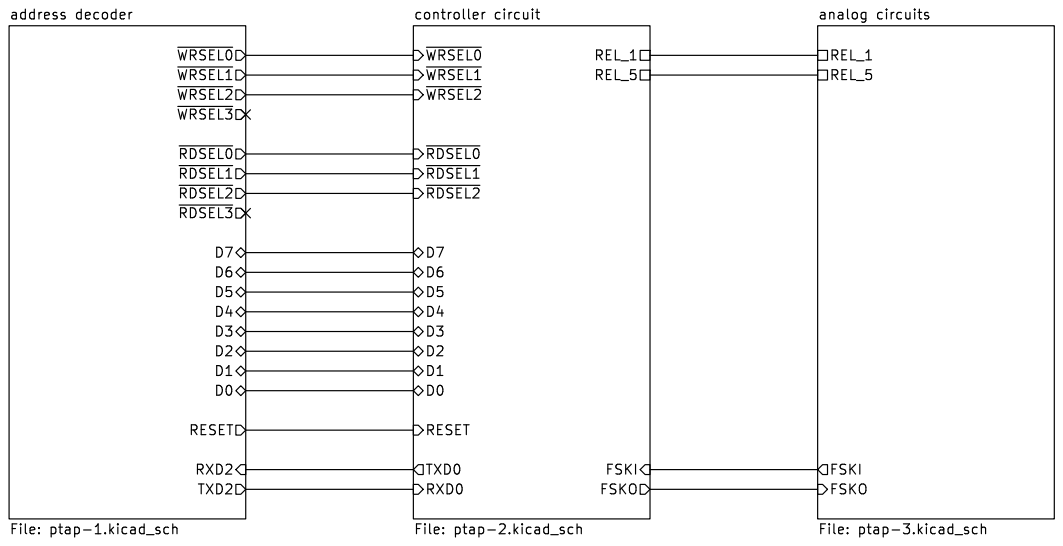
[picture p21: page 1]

analog circuits File: ptap-3.kicad_sch REL_1 FSKO
~{WRSEL2} D0 ~{WRSEL1}

Id: 1/4 Title: PTAP - Tape and speaker interface

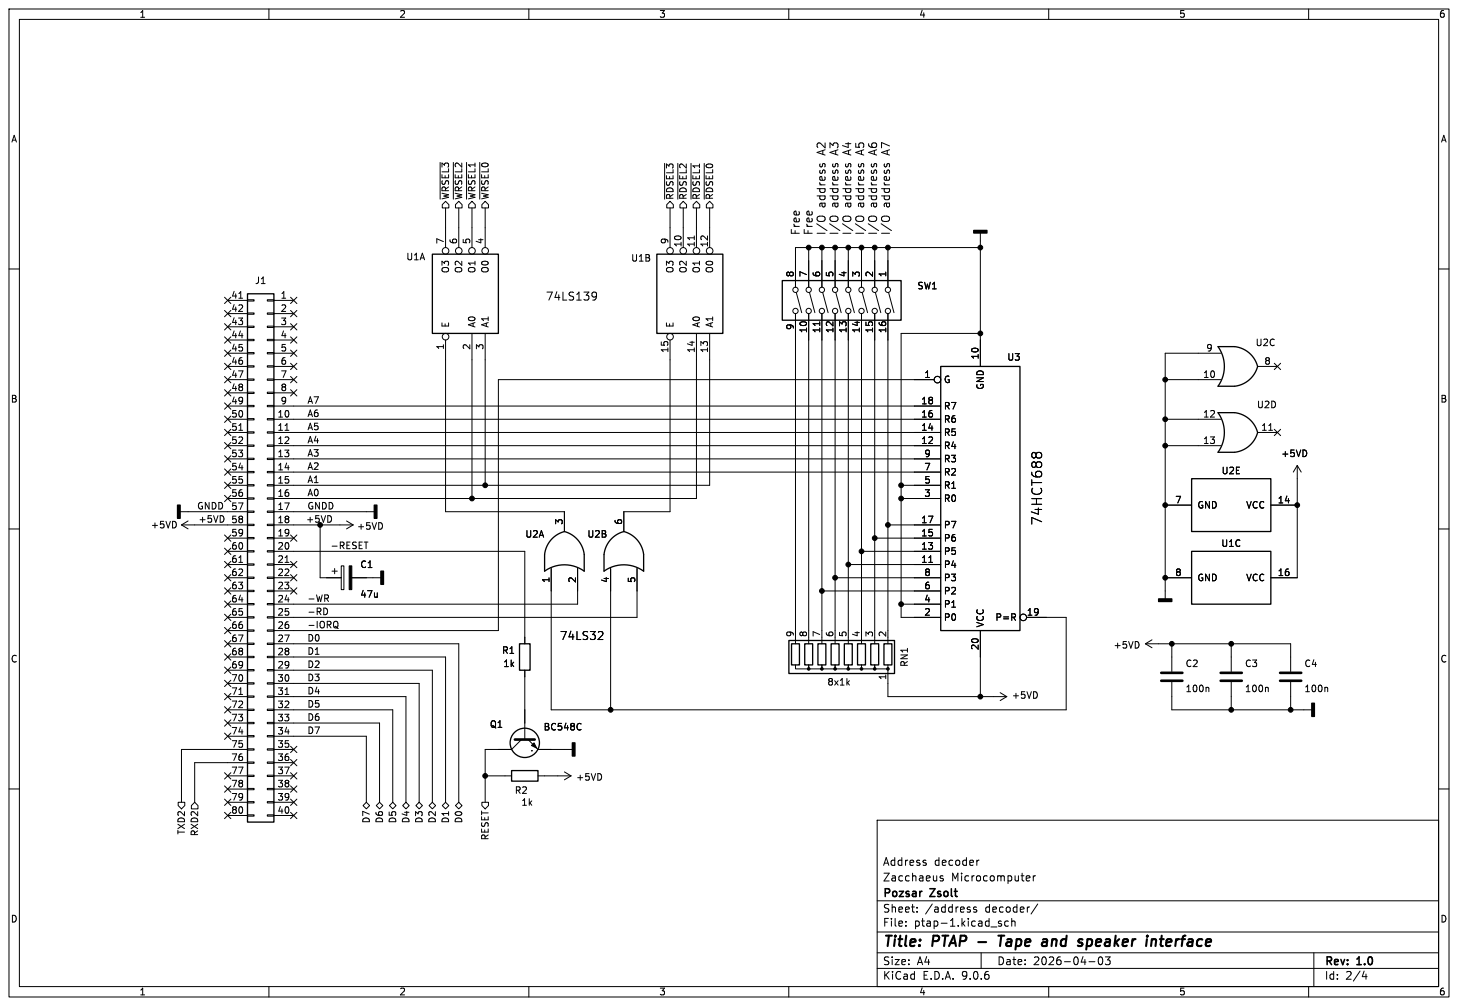
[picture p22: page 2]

Id: 2/4 Title: PTAP - Tape and speaker interface

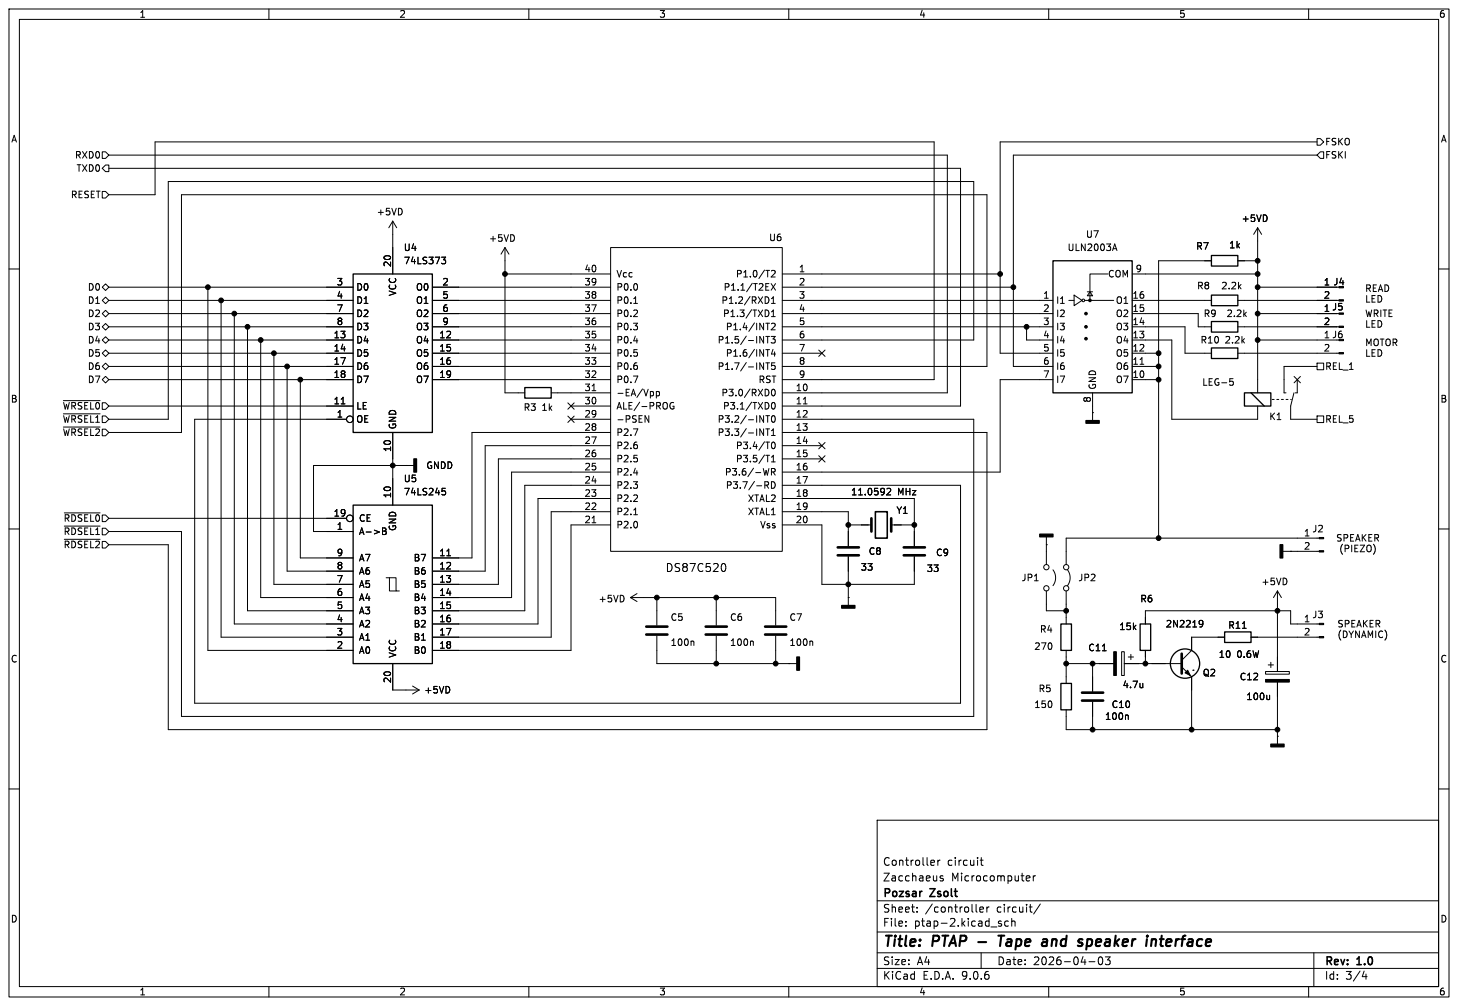
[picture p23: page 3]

Id: 3/4 Title: PTAP - Tape and speaker interface

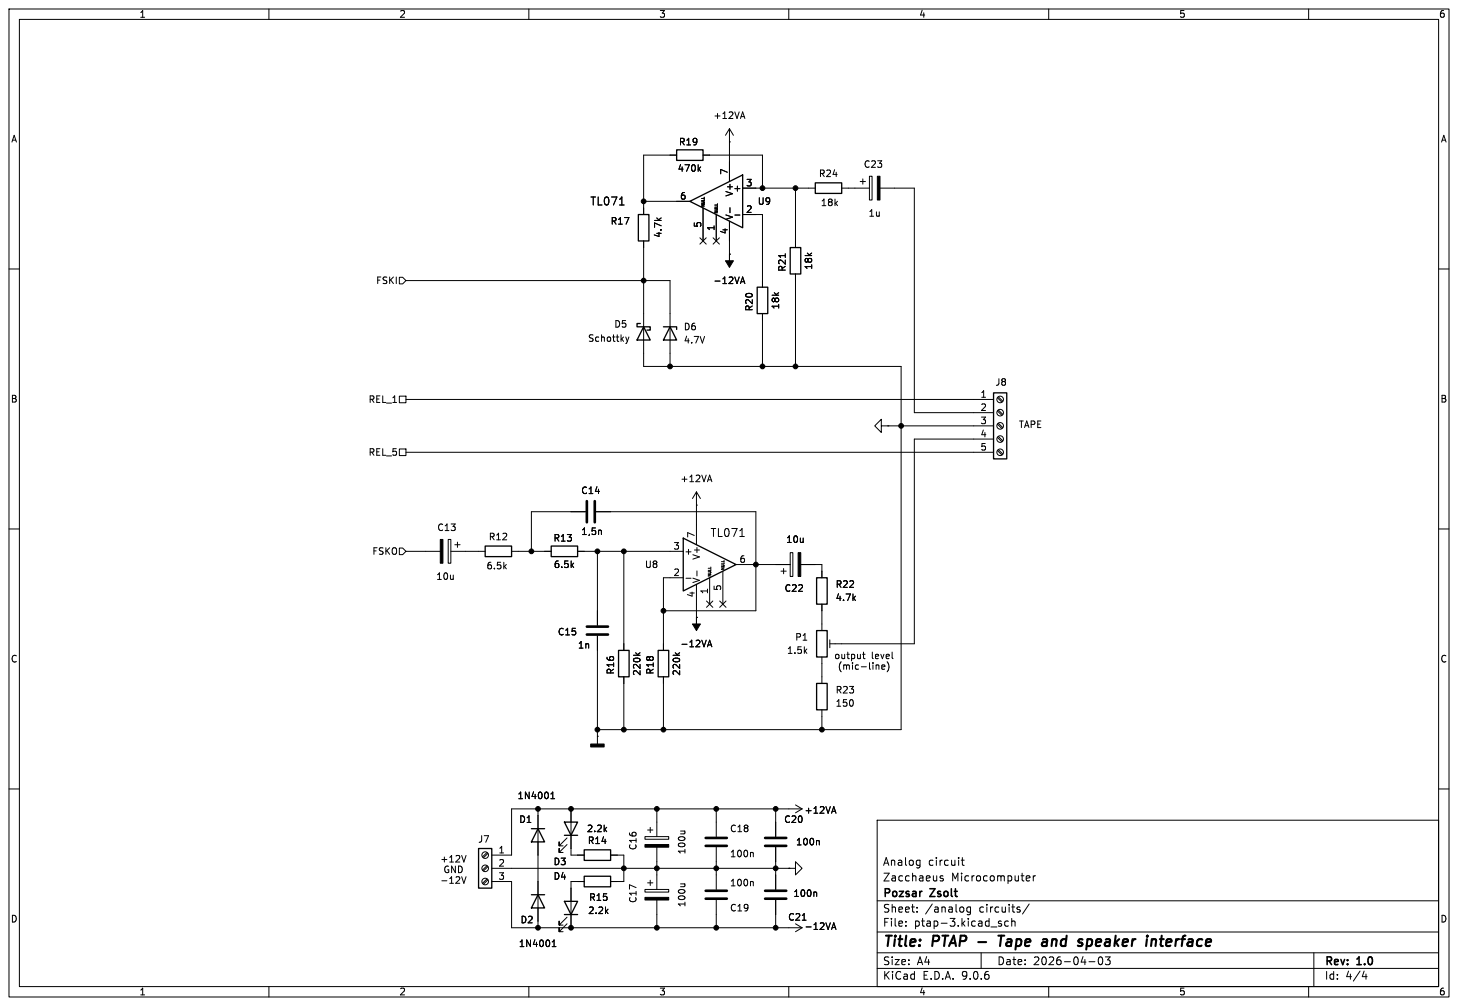
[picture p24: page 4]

output level (mic-line) R22

Id: 4/4 Title: PTAP - Tape and speaker interface

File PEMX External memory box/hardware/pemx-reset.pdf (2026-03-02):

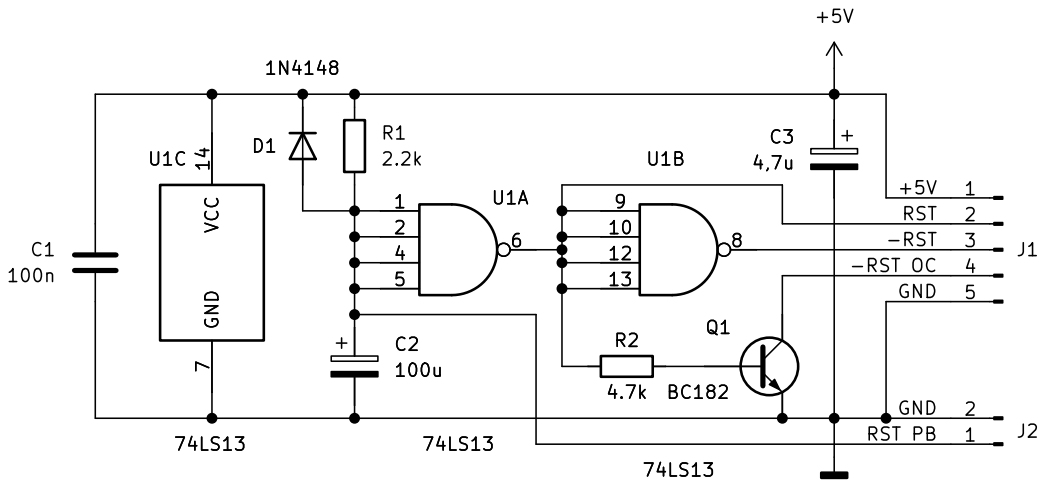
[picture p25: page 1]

Id: 1/1 Title: Alternative reset module

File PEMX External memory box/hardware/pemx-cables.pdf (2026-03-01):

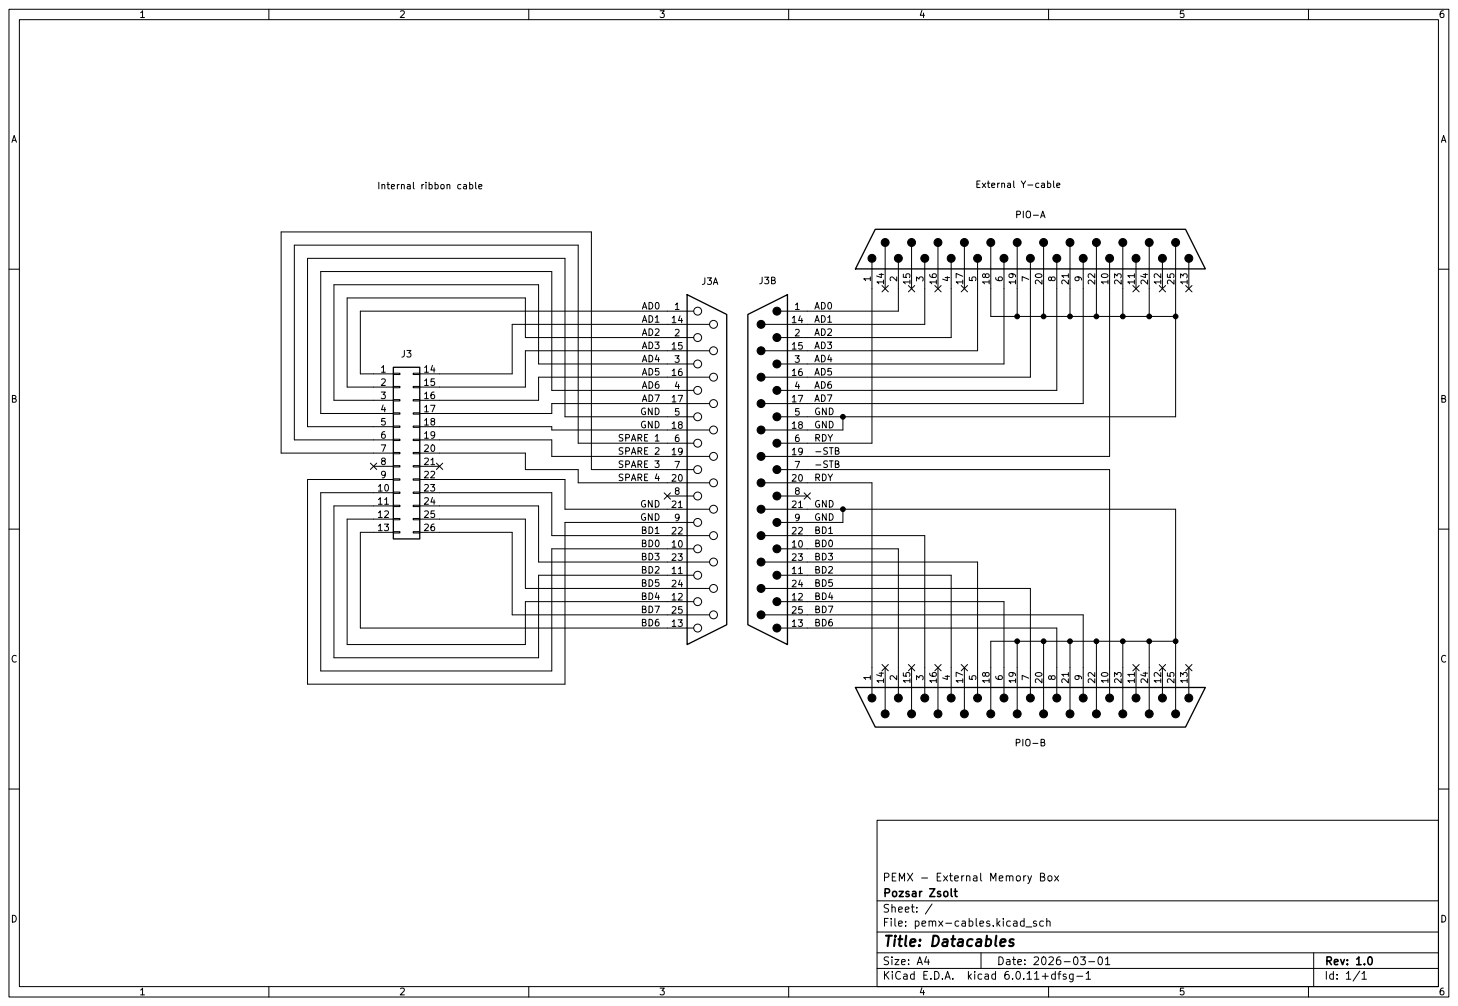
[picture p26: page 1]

10 | 23
11 | 24
12 | 25

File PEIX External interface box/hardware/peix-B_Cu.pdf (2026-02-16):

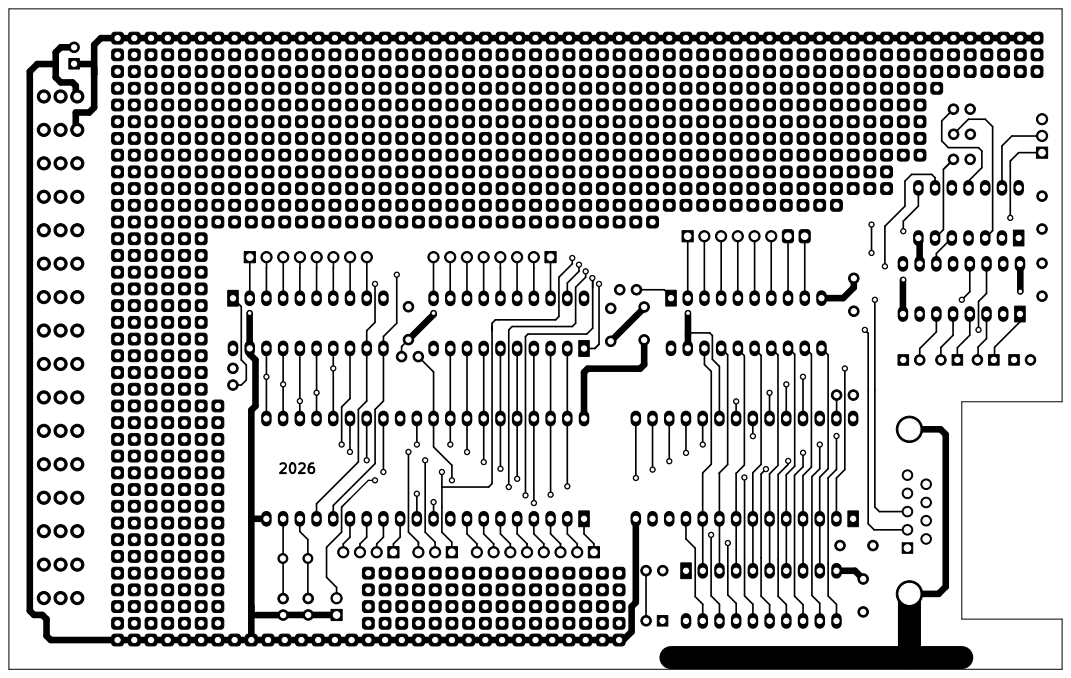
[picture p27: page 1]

Id: 1/1 Title: Control and communication card

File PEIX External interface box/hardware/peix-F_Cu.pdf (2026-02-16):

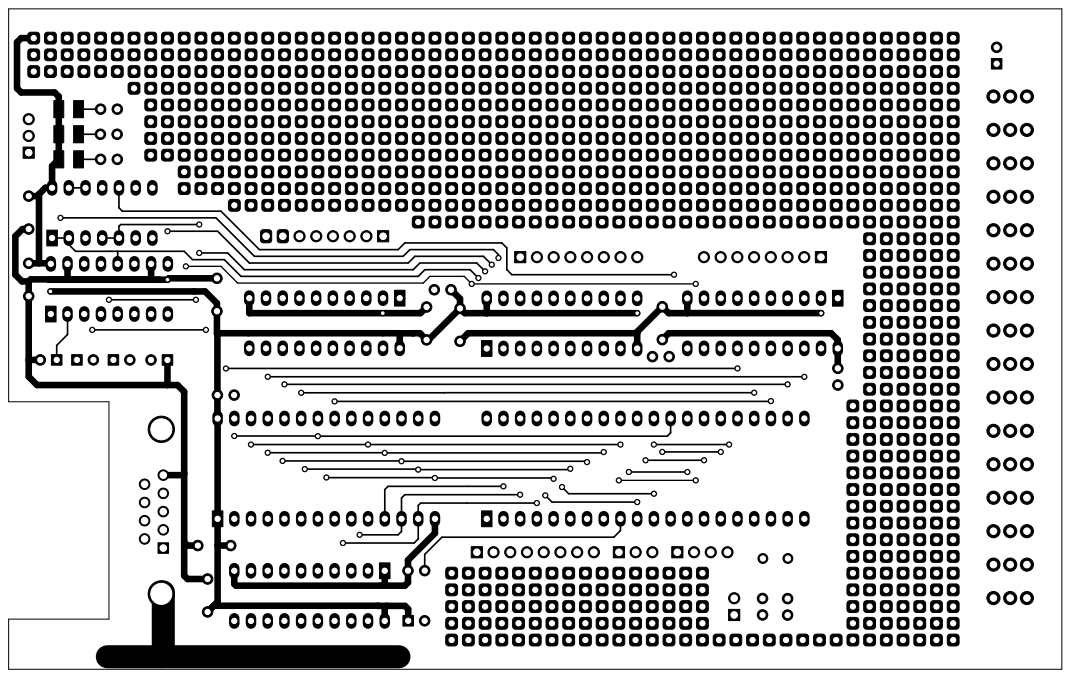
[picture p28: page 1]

Id: 1/1 Title: Control and communication card

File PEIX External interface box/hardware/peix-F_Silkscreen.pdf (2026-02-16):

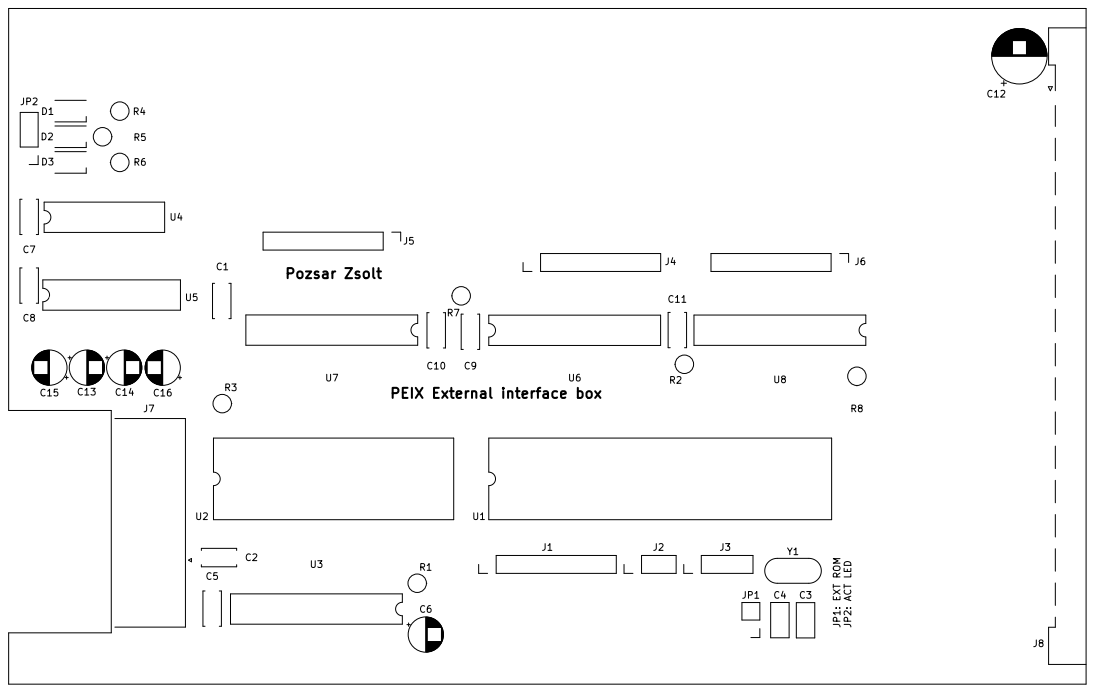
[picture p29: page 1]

Id: 1/1 Title: Control and communication card

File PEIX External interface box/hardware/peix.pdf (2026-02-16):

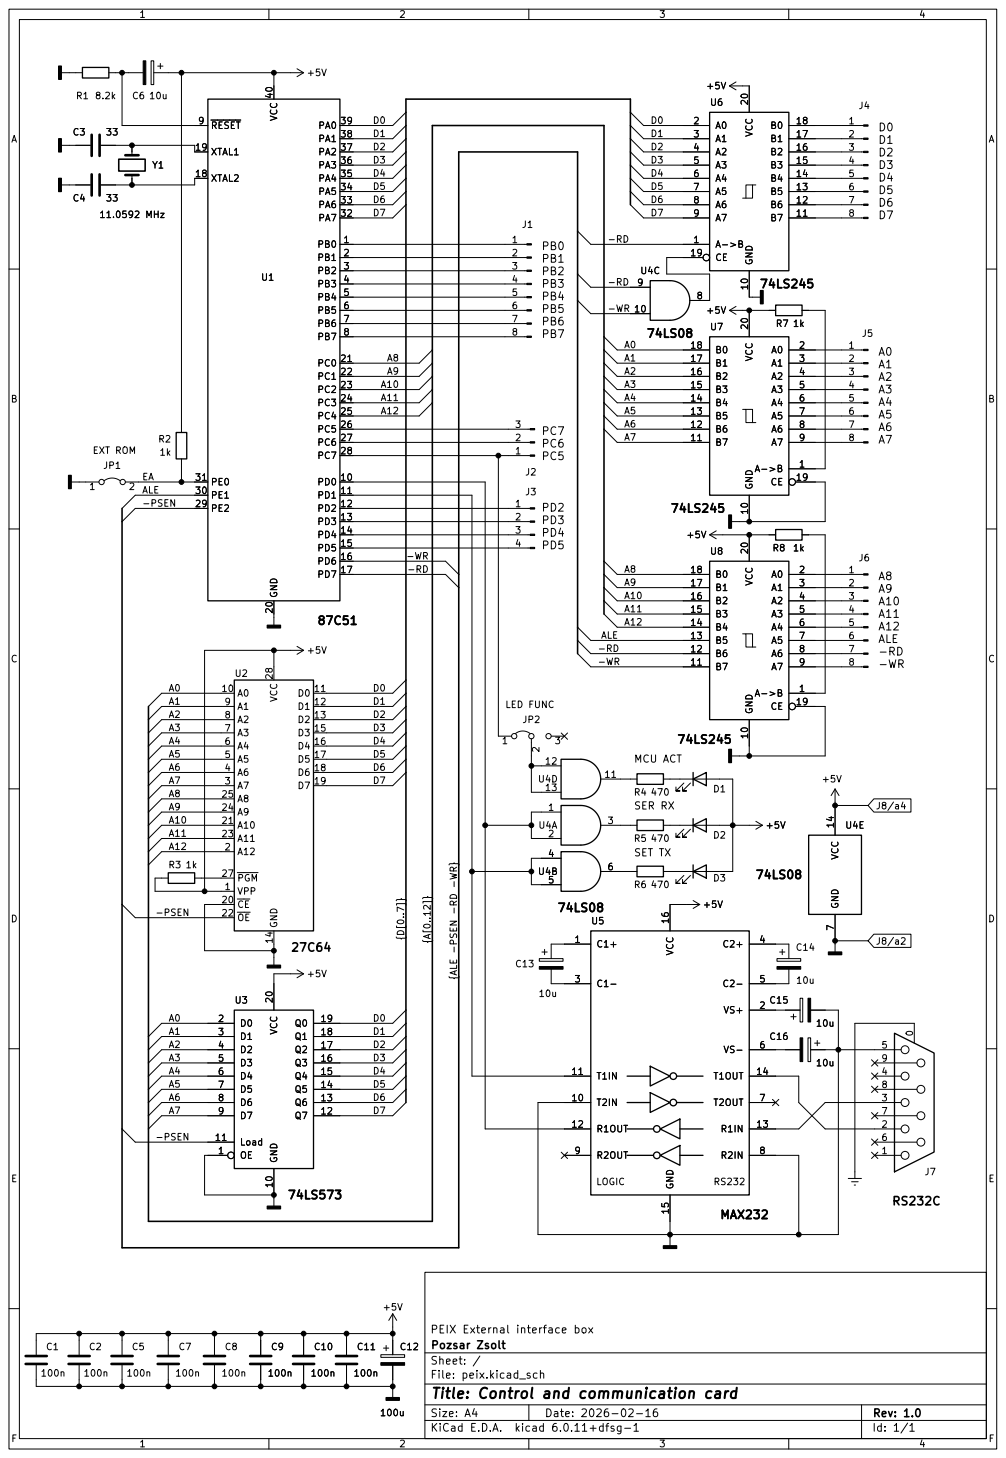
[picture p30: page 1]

6 PB6 | 6
7 PB7 | 8

Id: 1/1 Title: Control and communication card

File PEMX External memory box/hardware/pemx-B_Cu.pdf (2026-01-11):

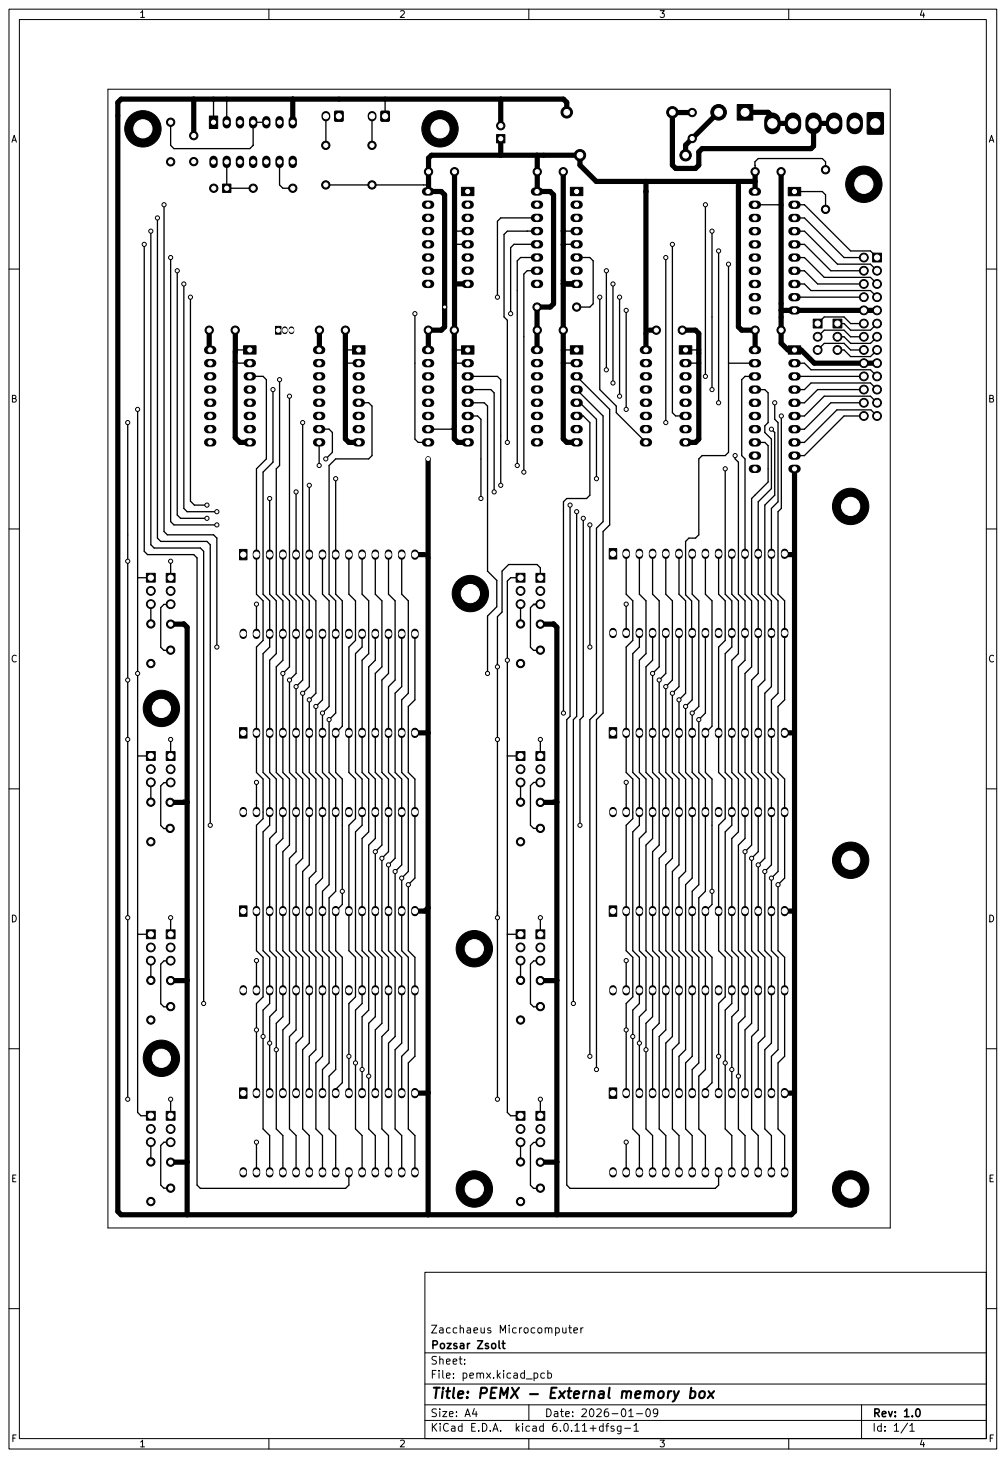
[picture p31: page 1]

Id: 1/1 Title: PEMX - External memory box

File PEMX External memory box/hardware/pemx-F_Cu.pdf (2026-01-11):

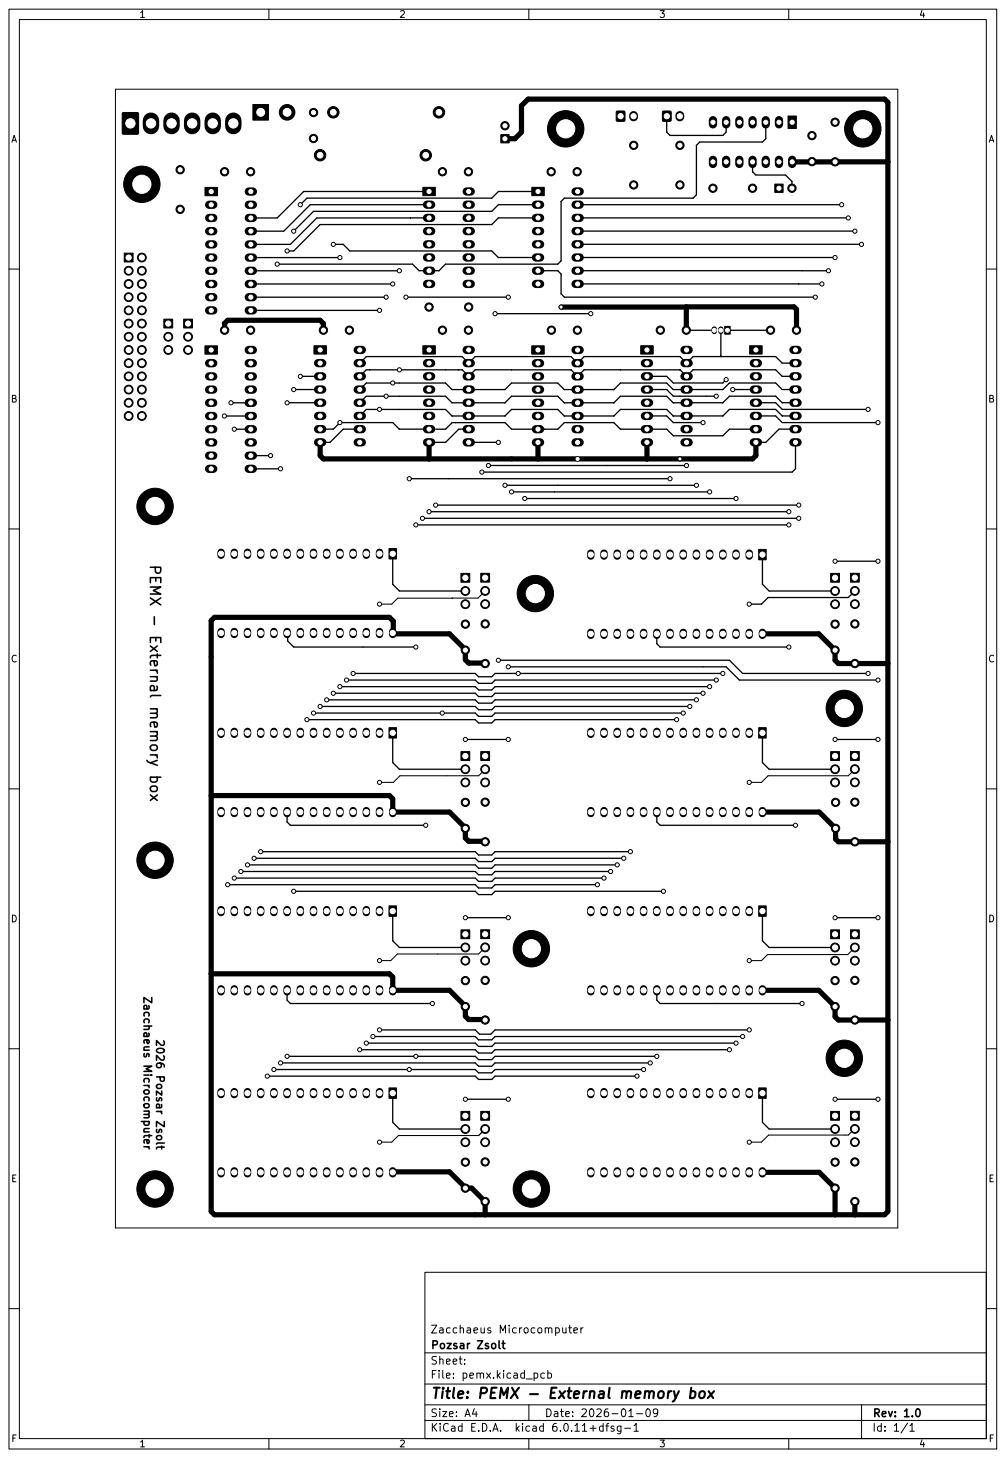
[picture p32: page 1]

Id: 1/1 Title: PEMX - External memory box

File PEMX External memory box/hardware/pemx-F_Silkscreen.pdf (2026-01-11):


Id: 1/1 Title: PEMX - External memory box

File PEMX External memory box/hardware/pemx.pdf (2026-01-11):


Id: 1/1 Title: PEMX - External memory box

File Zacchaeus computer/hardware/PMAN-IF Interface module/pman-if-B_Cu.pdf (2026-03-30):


Id: 1/1 Title: PMAN-IF Interface module
